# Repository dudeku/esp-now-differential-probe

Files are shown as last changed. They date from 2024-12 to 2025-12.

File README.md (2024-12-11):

# ESP-NOW Differential Probe Project

K. Dudek

### Framework: arduino-espressif32
>ver: 2.0.17
#### Lib Fixes:

```
in Ethernet.h
    class EthernetServer : public Server
    ->
    class EthernetServer : public Print
```

OR
```
in Ethernet.h in line 261:
	virtual void begin();
    ->
	virtual void begin(uint16_t port=0);

and in EthernetServer.cpp in line 28:
    void EthernetServer::begin()
    ->
    void EthernetServer::begin(uint16_t port_not_used)
```

#### Problems in framework version 3.x:
```
spi3 problem, not setting pinMode MISO (6)
[ ][E][esp32-hal-gpio.c:190] __digitalRead(): IO 6 is not set as GPIO.
```
### tool-esptoolpy @ 4.8.1

## Possible fix for framework 3.x
```
digitalRead() in LTC2449 lib cannot access MISO pin to check if transmission has been completed.

need to change LIC2449 library implementation for new version.
```

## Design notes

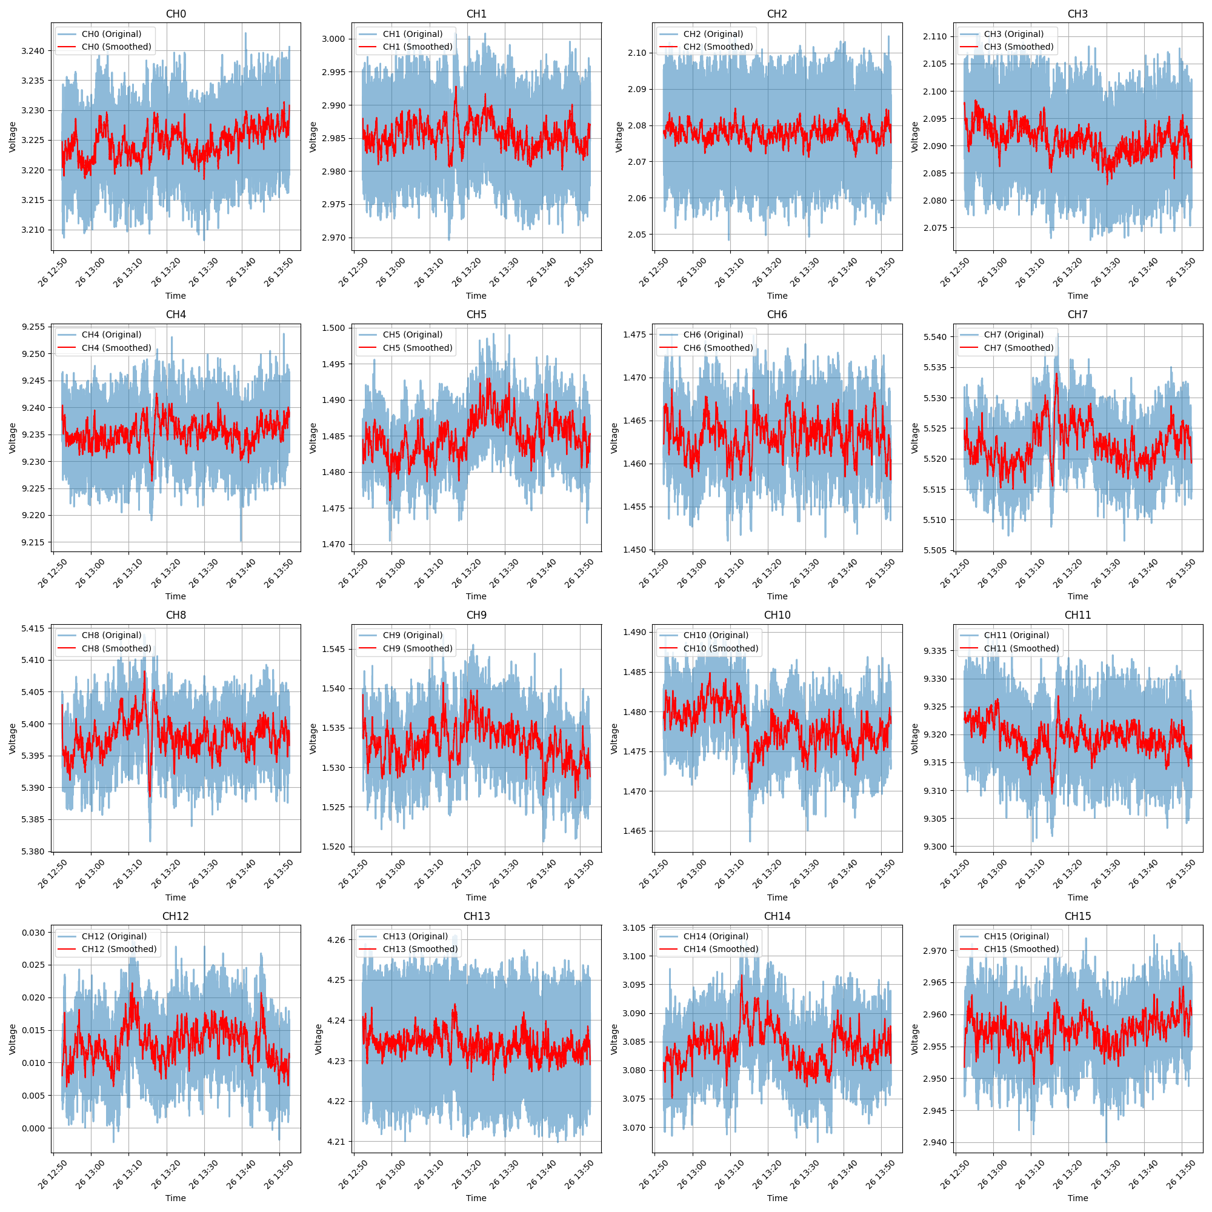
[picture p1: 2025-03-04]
scripts/graphs/espsonda_13-52-22_26-02-2025_2.png

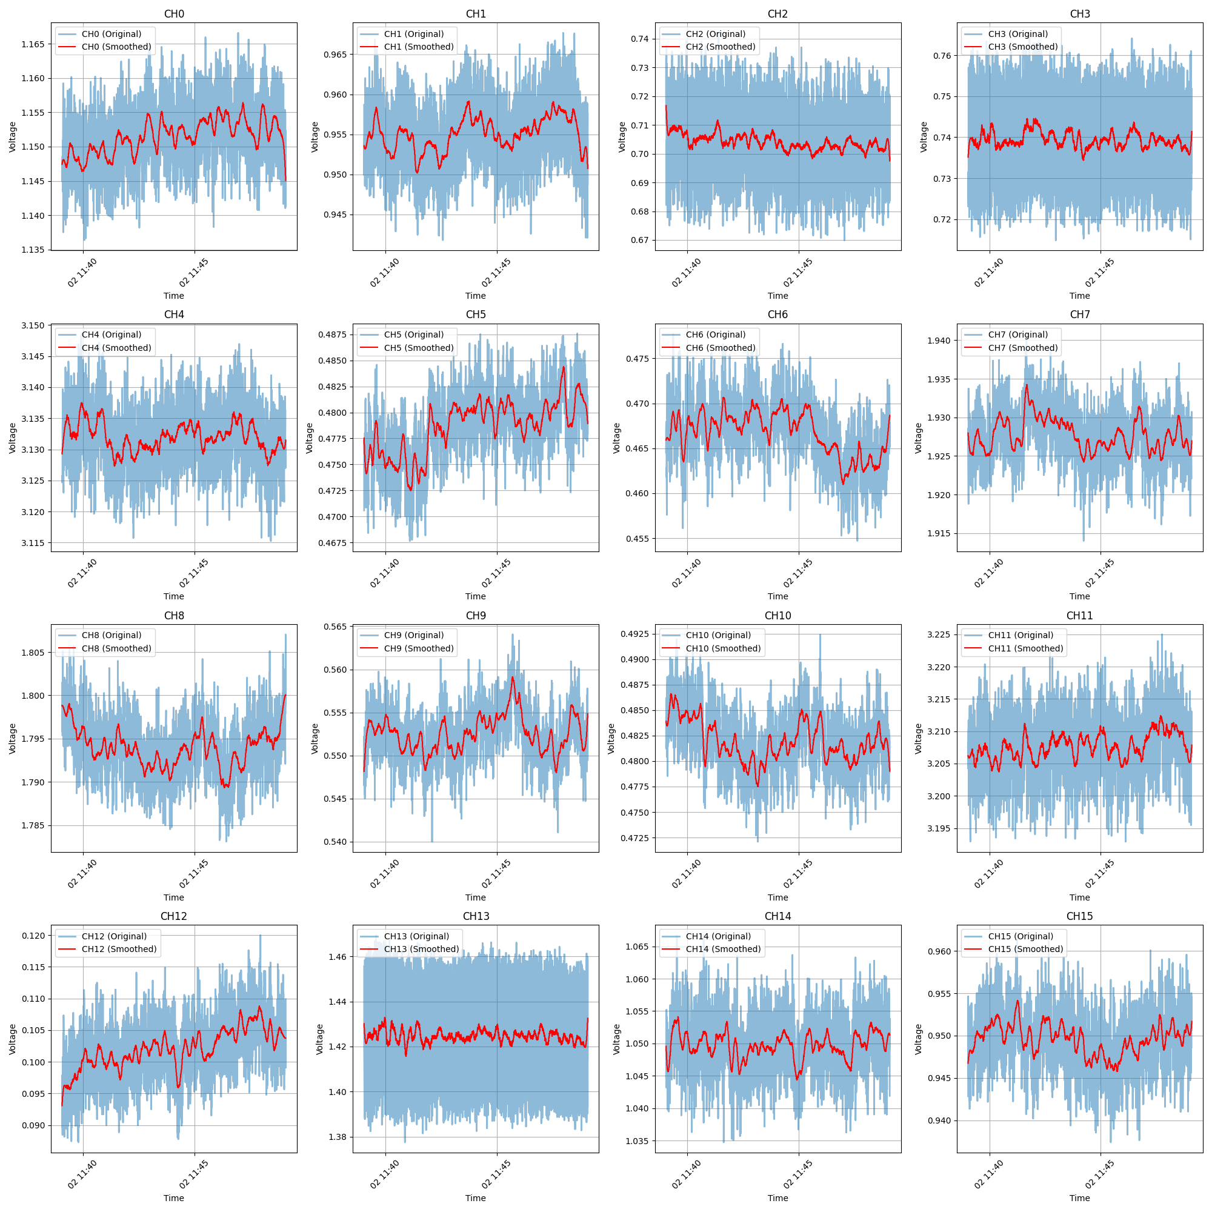
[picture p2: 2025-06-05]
scripts/graphs/espsonda_13-39-03_02-06-2025_2.png

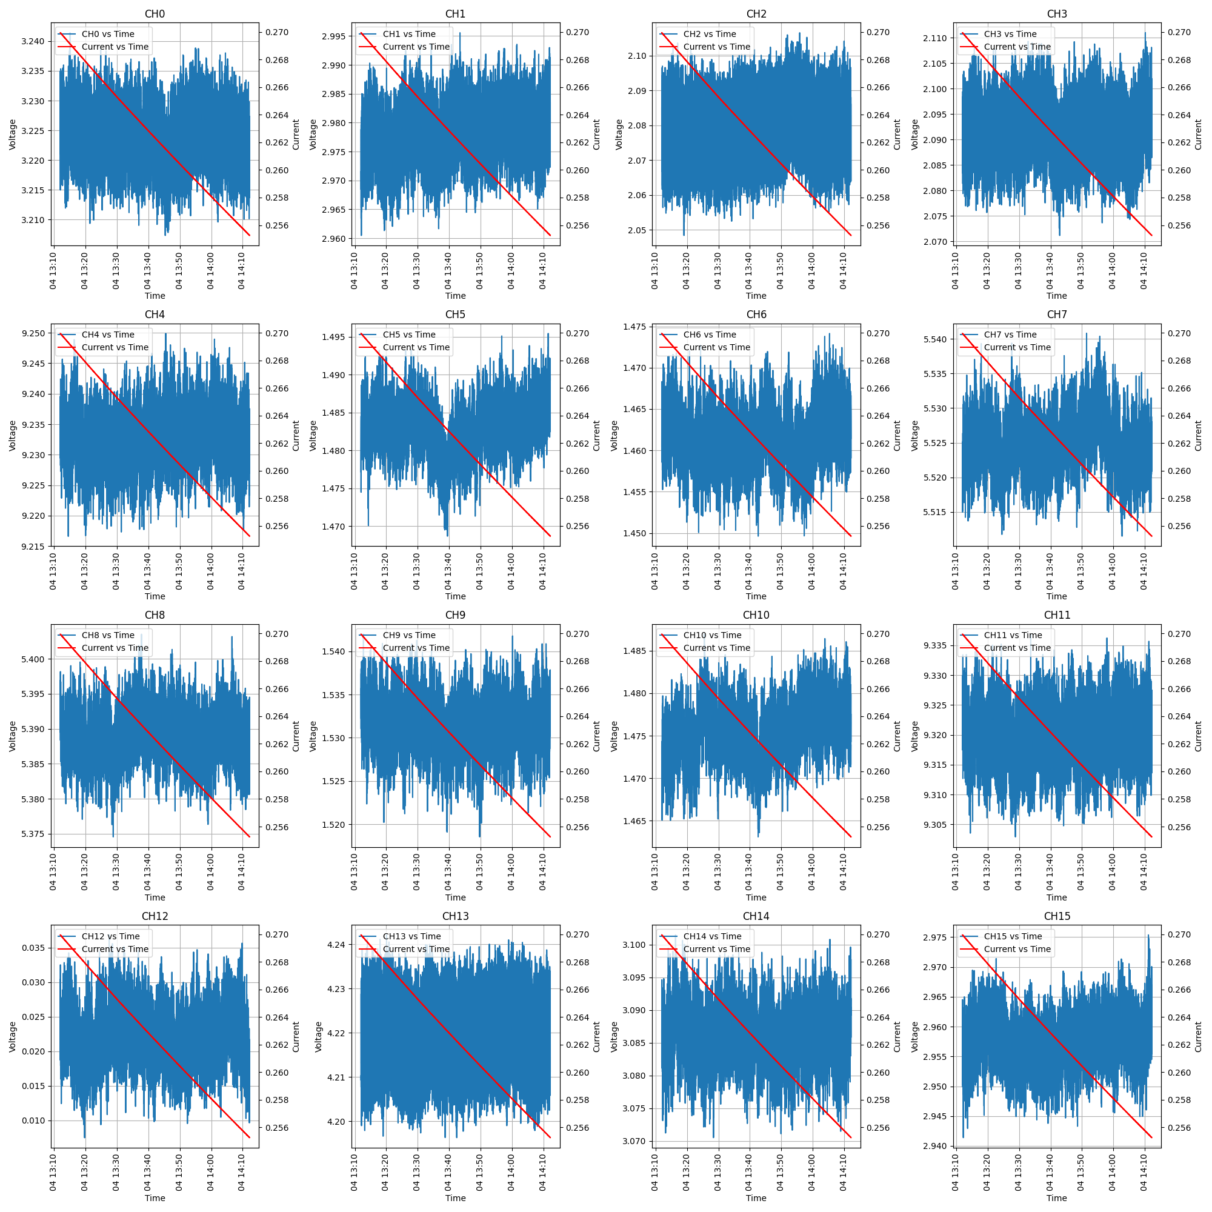
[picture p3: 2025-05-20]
scripts/graphs/espsonda_14-11-57_04-03-2025_1.png

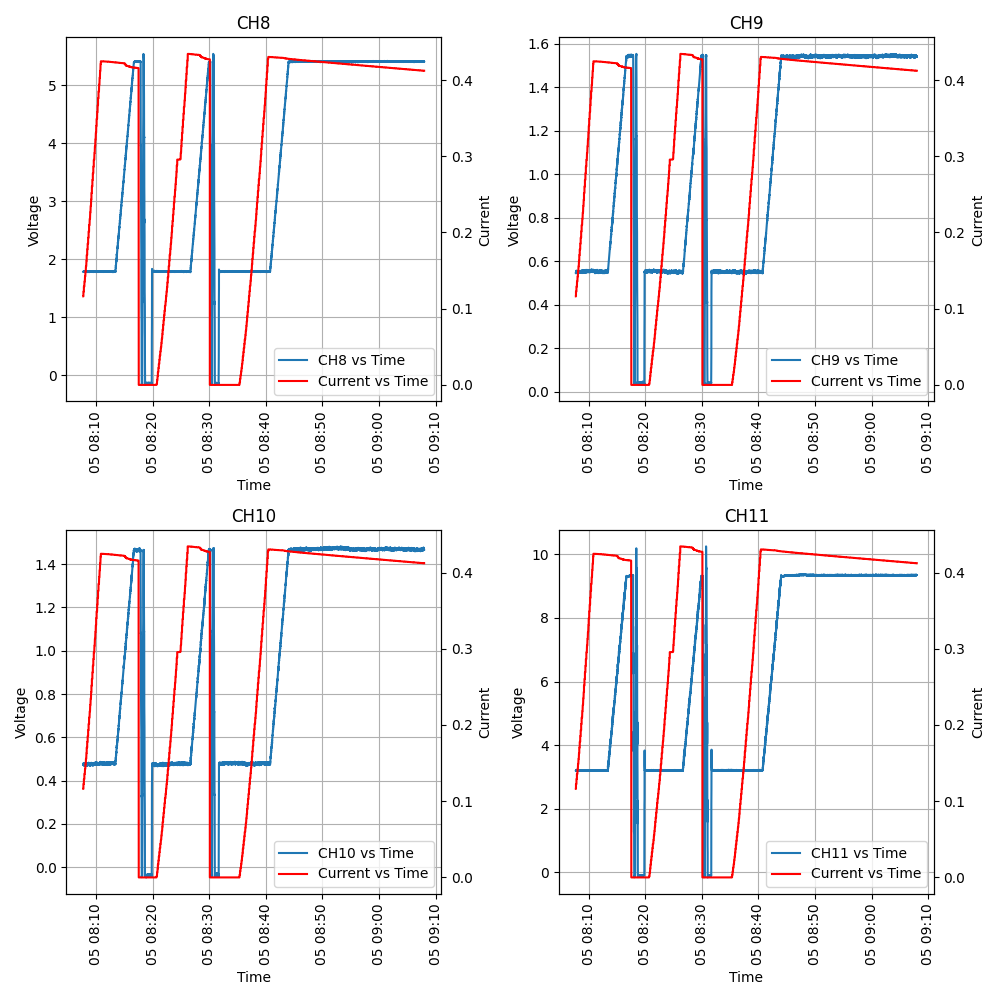
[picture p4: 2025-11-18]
scripts/graphs/espsonda_08-07-44_05-06-2025_fig3.png

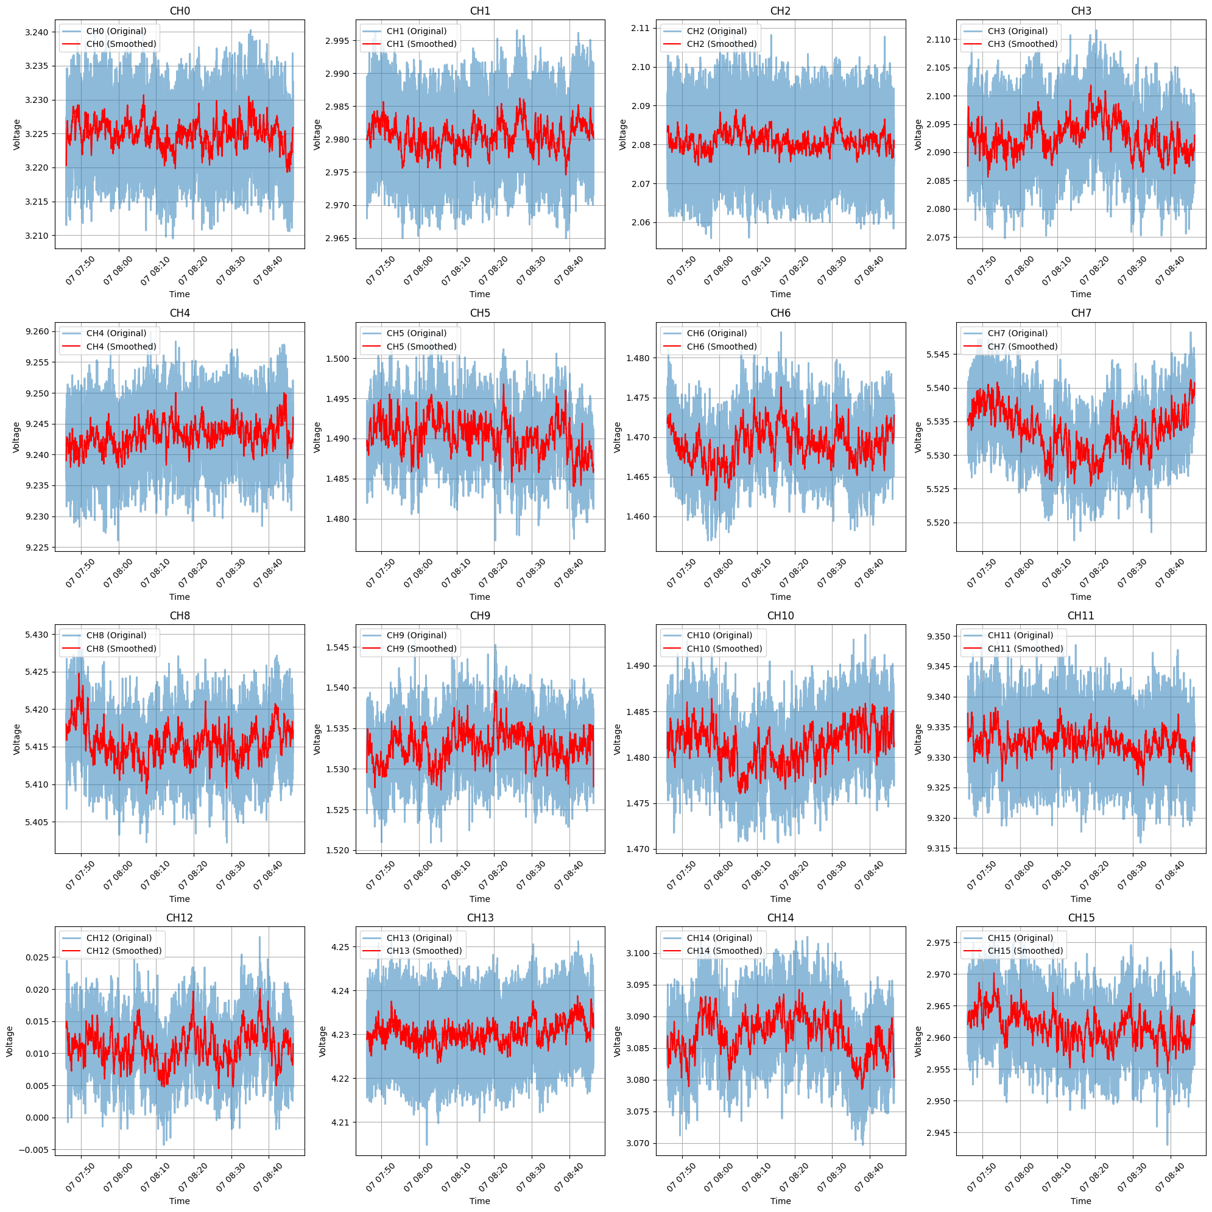
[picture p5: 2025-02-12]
scripts/graphs/1_5_GeV.png

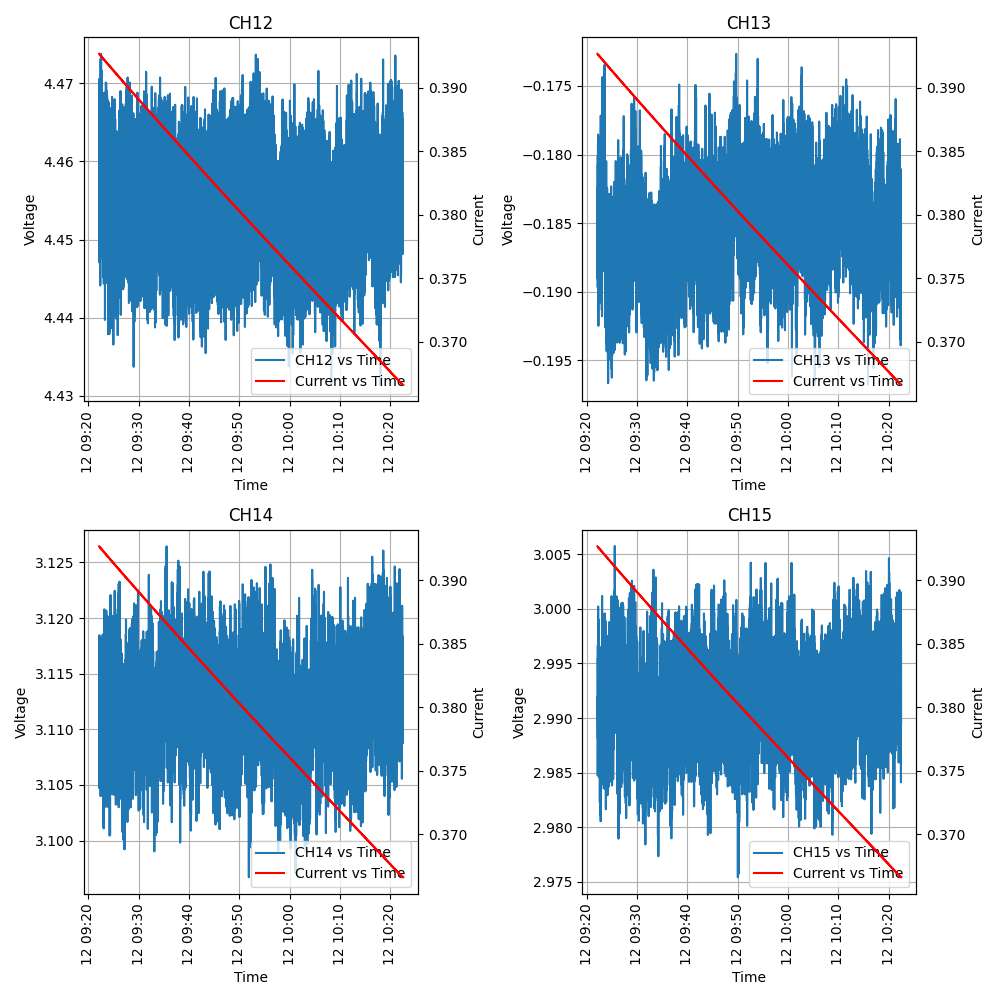
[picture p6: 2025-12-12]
scripts/graphs/espsonda_09-22-08_12-12-2025_fig4.png

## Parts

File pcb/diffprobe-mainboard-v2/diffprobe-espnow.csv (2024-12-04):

Id | Oznaczenie | Footprint | Liczba | Oznaczenie | Dostawca i numer artykułu
1 | C588,C546,C613,C640,C526,C521,C615,C635,C591,C554,C614,C600,C555,C622,C652,C566,C536,C535,C572,C647,C586,C527,C653,C610,C564,C649,C581,C578,C568,C625,C655,C562,C524,C542,C631,C590,C651,C633,C534,C514,C620,C582,C587,C660,C553,C629,C543,C531,C646,C537,C604,C540,C577,C549,C538,C529,C551,C592,C638,C560,C627,C576,C502,C563,C593,C552,C511,C626,C523,C619,C632,C545,C559,C602,C595,C525,C507,C561,C641,C599,C583,C659,C624,C510,C571,C522,C594,C628,C512,C658,C603,C636,C618,C518,C574,C516,C607,C506,C501,C609,C558,C548,C532,C584,C612,C648,C557,C596,C520,C517,C519,C528,C505,C579,C598,C503,C567,C608,C611,C654,C605,C513,C617,C643,C616,C565,C642,C637,C589,C606,C533,C634,C573,C575,C550,C585,C645,C547,C657,C601,C621,C630,C539,C556,C580,C541,C544,C656,C508,C504,C644,C509,C623,C639,C569,C530,C570,C650,C515,C597 | C_1206_3216Metric | 160 | 10 pF
2 | J12 | CONN12_5-2301994-8_TEC | 1 | 8P8C_LED_Shielded_x2
3 | R516,R657,R605,R602,R587,R617,R639,R576,R549,R552,R659,R633,R531,R590,R637,R569,R595,R640,R610,R543,R589,R574,R634,R528,R570,R598,R612,R556,R585,R555,R540,R575,R553,R594,R643,R523,R578,R519,R616,R517,R615,R582,R521,R646,R518,R507,R537,R638,R524,R560,R641,R592,R654,R631,R504,R565,R514,R550,R601,R649,R522,R545,R581,R619,R632,R520,R660,R635,R535,R611,R648,R606,R596,R534,R541,R505,R642,R502,R530,R644,R546,R566,R630,R658,R529,R627,R597,R593,R599,R588,R544,R557,R577,R600,R609,R510,R513,R625,R564,R628,R655,R562,R591,R629,R508,R608,R623,R650,R561,R653,R618,R547,R586,R559,R636,R651,R583,R515,R538,R647,R503,R572,R501,R539,R652,R624,R622,R558,R603,R512,R506,R571,R563,R573,R584,R511,R620,R656,R526,R613,R533,R604,R532,R542,R607,R567,R645,R509,R614,R568,R579,R626,R527,R548,R621,R554,R536,R551,R525,R580 | R_1206_3216Metric | 160 | 1 MOhms
4 | C106,C104 | C_0603_1608Metric | 2 | 10u
5 | R119,R120,R117,R121 | R_0603_1608Metric | 4 | 49R9
6 | J124,J116,J132,J131,J117,J112,J122,J105,J129,J118,J108,J123,J128,J106,J103,J113,J119,J107,J114,J130,J111,J110,J101,J121,J109,J115,J120,J102,J104,J127,J126,J125 | PinHeader_1x04_P2.54mm_Vertical | 32 | Conn_01x04_Socket
7 | J509,J504,J503,J505,J510,J507,J512,J508,J506,J516,J513,J502,J514,J501,J515,J511 | PhoenixContact_GMSTBA_2,5_2-G-7,62_1x02_P7.62mm_Horizontal | 16 | Screw_Terminal_01x02
8 | C105,C217,C218 | C_0603_1608Metric | 3 | 0.1u
9 | C108,C103,C101 | C_0603_1608Metric | 3 | 100n
10 | C120,C121,C116,C117,C112,C118,C119 | C_0603_1608Metric | 7 | 0.1uF
11 | D101 | D_0603_1608Metric | 1 | NSR20F30NXT5G
12 | R107 | R_0603_1608Metric | 1 | 1MEG
13 | C114,C124 | C_0603_1608Metric | 2 | 10nF
14 | R206,R213,R207,R210,R215,R204,R205,R214,R203,R212,R201,R216,R202,R208,R211,R209 | R_0603_1608Metric | 16 | 470R
15 | C202,C216,C206,C211,C201,C212,C214,C213,C210,C209,C207,C205,C203,C215,C204,C208,C223 | C_0603_1608Metric | 17 | 470pF
16 | R105,R101,R109,R102,R111,R110,R218 | R_0603_1608Metric | 7 | 10k
17 | C122,C113 | C_0603_1608Metric | 2 | 10uF
18 | R114,R115,R113,R112 | R_0603_1608Metric | 4 | 33R
19 | R123,R122 | R_0603_1608Metric | 2 | 330
20 | U103 | LQFP-48_7x7mm_P0.5mm | 1 | W5500
21 | J11 | USB_C_Receptacle_GCT_USB4105-xx-A_16P_TopMnt_Horizontal | 1 | USB_C_Receptacle_USB2.0
22 | SW103 | SW_PUSH_E-Switch_500SDP1S1M2QEA | 1 | 500SDP1S1M2QEA
23 | C302,C301 | C_Rect_L13.0mm_W4.0mm_P10.00mm_FKS3_FKP3_MKS4 | 2 | 22nF
24 | SW102,SW101 | SW_Push_1P1T_NO_CK_KMR2 | 2 | SW_Push
25 | U101 | ESP32-S3-WROOM-1U | 1 | ESP32-S3-WROOM-1
26 | R118 | R_0603_1608Metric | 1 | 10
27 | R106,R217 | R_0603_1608Metric | 2 | 1k
28 | C305,C102,C303,C107 | C_0603_1608Metric | 4 | 1u
29 | C111,C110 | C_0603_1608Metric | 2 | 18pF
30 | R108 | R_0603_1608Metric | 1 | 0R
31 | R104,R103 | R_0603_1608Metric | 2 | 5.1k
32 | C123 | C_0603_1608Metric | 1 | 22nF
33 | D102 | LED_0603_1608Metric | 1 | LED
34 | J54 | Pin_D1.4mm_L8.5mm_W2.8mm_FlatFork | 1 | AC_P
35 | C127 | C_0603_1608Metric | 1 | 1nF
36 | F1 | Fuse_Littelfuse_372_D8.50mm | 1 | 37213150431
37 | C304,C306 | CP_Elec_10x12.5 | 2 | 100u
38 | FL1 | Choke_EPCOS_B82722A | 1 | EPCOS B82722A2202N001
39 | RV2,RV1 | RV_Disc_D9mm_W4.2mm_P5mm | 2 | B72207S0251K101
40 | C126,C125 | C_0603_1608Metric | 2 | 6.8nF
41 | Y101 | Crystal_SMD_HC49-SD | 1 | DF18CC1-25.000MHZ-T
42 | J56 | Pin_D1.4mm_L8.5mm_W2.8mm_FlatFork | 1 | AC_E
43 | C219 | C_0603_1608Metric | 1 | 4n7F
44 | PS1 | CONV_TML_20205 | 1 | TML_20205
45 | R116 | R_0603_1608Metric | 1 | 12.4k 1%
46 | J55 | Pin_D1.4mm_L8.5mm_W2.8mm_FlatFork | 1 | AC_N
47 | U105 | SOT-23-6 | 1 | USBLC6-2SC6
48 | U102 | QFN-38-1EP_5x7mm_P0.5mm_EP3.15x5.15mm | 1 | LTC2448CUHF-PBF
49 | C115 | C_0603_1608Metric | 1 | 4.7uF
50 | U107 | TSSOP-20_4.4x6.5mm_P0.65mm | 1 | TXB0108DQSR
51 | U106 | SOT-23-5 | 1 | LM4030-2.5
52 | L101 | L_0603_1608Metric | 1 | BLM18PG121SN1D
53 | C109 | C_0603_1608Metric | 1 | 4.7u
54 | U104 | SOT-223-3_TabPin2 | 1 | LDL1117S33R

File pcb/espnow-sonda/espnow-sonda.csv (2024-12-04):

Id | Oznaczenie | Footprint | Liczba | Oznaczenie | Dostawca i numer artykułu
1 | C19,C15,C14,C18 | C_0603_1608Metric | 4 | 1 µF
2 | TP3,TP1,TP2,TP4,TP5 | TestPoint_Pad_D1.5mm | 5 | Test Point
3 | R21,R22,R19,R24,R20 | R_0603_1608Metric | 5 | 348 Ohms
4 | D2,D4,D3,D1 | D_SOD-323 | 4 | BAS316,115
5 | C6,C3 | C_0603_1608Metric | 2 | 470pF
6 | J2,J1 | PinHeader_1x04_P2.54mm_Vertical | 2 | Conn_01x04_Pin
7 | C5,C2 | C_0603_1608Metric | 2 | 510pF
8 | R8,R10 | R_0603_1608Metric | 2 | 24.9 Ohms
9 | L1,L2 | L_0603_1608Metric | 2 | 22 nH
10 | R5,R4,R14,R13 | R_0603_1608Metric | 4 | 150 Ohms
11 | U1 | MSOP-8-1EP_3x3mm_P0.65mm_EP1.68x1.88mm | 1 | LTC6269xMS8E
12 | R16 | R_0603_1608Metric | 1 | 2.05k
13 | R18,R17 | R_0603_1608Metric | 2 | 470 Ohms
14 | C10,C11,C9 | C_0603_1608Metric | 3 | 10 pF
15 | C4,C1 | C_Trimmer_Voltronics_JZ | 2 | JZ400
16 | R7,R11 | R_0603_1608Metric | 2 | 845 Ohms
17 | U3 | SOT-23-6 | 1 | LMH6611
18 | R15 | R_0603_1608Metric | 1 | 110
19 | R6,R12 | R_0603_1608Metric | 2 | 9.1 kOhms
20 | R1,R3 | R_0603_1608Metric | 2 | 15 kOhms
21 | U2 | SOT-23-3 | 1 | XC6206P251
22 | U4 | SOT-23-3 | 1 | XC6902N251
23 | C13,C17,C12,C16 | C_0603_1608Metric | 4 | 0.1 µF
24 | C8,C7 | C_0603_1608Metric | 2 | 10pF
25 | R23 | R_0603_1608Metric | 1 | 1 kOhms
26 | R9 | Potentiometer_Bourns_3006W_Horizontal | 1 | 100 Ohms
27 | R2 | Potentiometer_Bourns_3006W_Horizontal | 1 | 1 MOhms

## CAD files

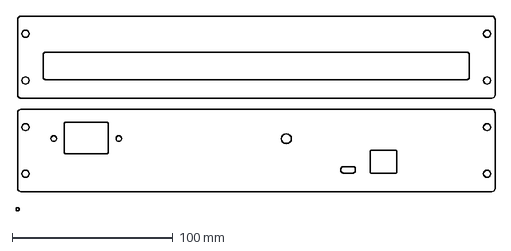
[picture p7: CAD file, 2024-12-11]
case/fpbp_sonda.dxf
297.6 x 121.1 mm

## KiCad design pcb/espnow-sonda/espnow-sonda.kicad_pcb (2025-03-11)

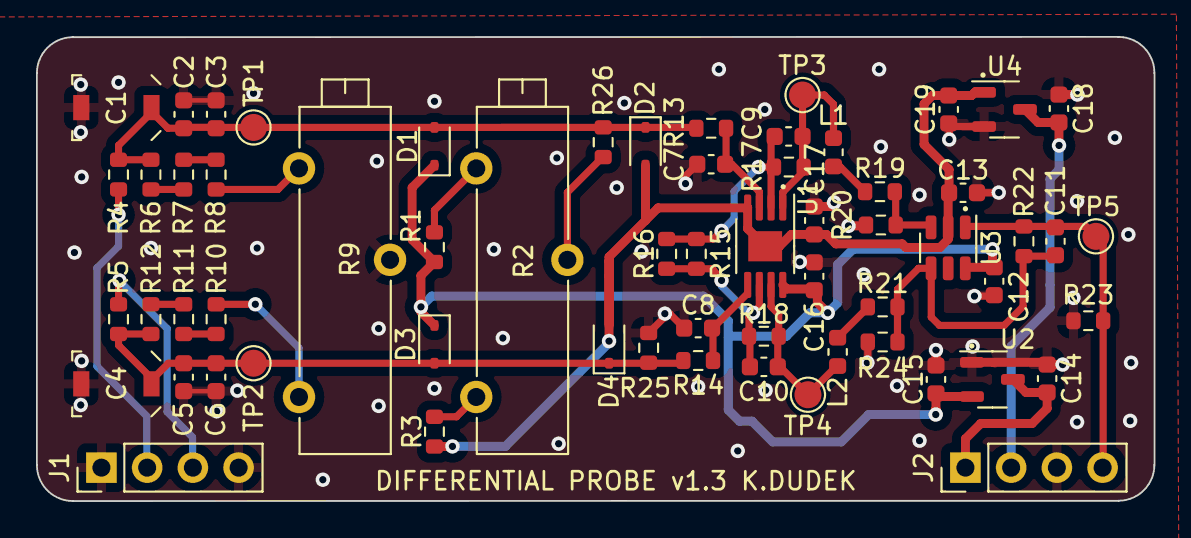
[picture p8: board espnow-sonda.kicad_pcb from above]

Board: 2 copper layers, 62.1 x 25.8 mm, 62 parts (0 on the bottom side), 29 nets.

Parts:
C1, C4: C_Trimmer_Voltronics_JZ
C2, C3, C5, C6: C_0603_1608Metric
C7, C8, C9, C10, C11: 10p; C_0603_1608Metric
C12, C13, C16, C17: 0.1µ; C_0603_1608Metric
C14, C15, C18, C19: 1µ; C_0603_1608Metric
D1, D2, D3, D4: BAS316,115; D_SOD-323
J1, J2: PinHeader_1x04_P2.54mm_Vertical
L1, L2: r0; L_0603_1608Metric
R1, R3: 1M; R_0603_1608Metric
R2: 1M; Potentiometer_Bourns_3006W_Horizontal
R4, R5, R13, R14: 150; R_0603_1608Metric
R6, R12: 9.1k; R_0603_1608Metric
R7, R11: 845; R_0603_1608Metric
R8, R10: 24.9; R_0603_1608Metric
R9: 100; Potentiometer_Bourns_3006W_Horizontal
R15: 16; R_0603_1608Metric
R16, R24: R_0603_1608Metric
R17, R18: 470; R_0603_1608Metric
R19, R20, R21, R22: 348; R_0603_1608Metric
R23: 1k; R_0603_1608Metric
R25, R26: 750k; R_0603_1608Metric
TP1, TP2, TP4, TP5: TestPoint_Pad_D1.5mm
TP3: Test Point; TestPoint_Pad_D1.5mm
U1: LTC6269; MSOP-8-1EP_3x3mm_P0.65mm_EP1.68x1.88mm
U2: XC6206P251; SOT-23-3
U3: LMH6611; SOT-23-6
U4: XC6902N251; SOT-23-3

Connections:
4V8: C12.2, C15.2, C16.2, D1.1, D3.1, R1.1, U1.8 (V+), U2.2 (VO), U3.6 (V+)
-4V8: C13.2, C17.2, C19.2, D2.2, D4.2, R3.2, U1.4 (V-), U1.9 (V-), U3.2 (V-), U4.1 (VO)
/IN_N: J1.3, R5.1
/IN_P: J1.2, R4.1
/VCC5V: C14.2, J2.1, U2.3 (VI)
/VEE-5V: C18.2, J2.2, U4.3 (VI)
/VOUT: C11.2, J2.4, R22.2, R23.2, TP5.1 (TP), U3.1
GND: C1.2, C2.1, C3.1, C4.2, C5.1, C6.1, C7.1, C8.1, C12.1, C13.1, C14.1, C15.1, C16.1, C17.1, C18.1, C19.1, J1.1, J1.4, J2.3, R9.2, R20.2, R23.1, R24.1, R25.1, U2.1 (GND), U4.2 (GND)
unnamed: L1.2, R19.1
unnamed: L2.2, R21.1
unnamed: R1.2, R2.3
unnamed: R2.1, R3.1
unnamed: R2.2, R26.1
unnamed: R6.1, R7.2
unnamed: R7.1, R8.2
unnamed: R8.1, R9.3
unnamed: R9.1, R10.1
unnamed: R10.2, R11.1
unnamed: R11.2, R12.1
unnamed: C1.1, C2.2, C3.2, D1.2, D2.1, R4.2, R6.2, R13.1, R26.2, TP1.1 (TP)
unnamed: C4.1, C5.2, C6.2, D3.2, D4.1, R5.2, R12.2, R14.1, R25.2, TP2.1 (TP)
unnamed: C9.2, L1.1, R17.2, TP3.1 (TP), U1.1
unnamed: C10.2, L2.1, R18.2, TP4.1 (TP), U1.7
unnamed: C7.2, R13.2, U1.3 (+)
unnamed: C9.1, R15.1, R16.1, R17.1, U1.2 (-)
unnamed: C8.2, R14.2, U1.5 (+)
unnamed: C10.1, R15.2, R16.2, R18.1, U1.6 (-)
unnamed: R19.2, R20.1, U3.3 (+)
unnamed: C11.1, R21.2, R22.1, R24.2, U3.4 (-)

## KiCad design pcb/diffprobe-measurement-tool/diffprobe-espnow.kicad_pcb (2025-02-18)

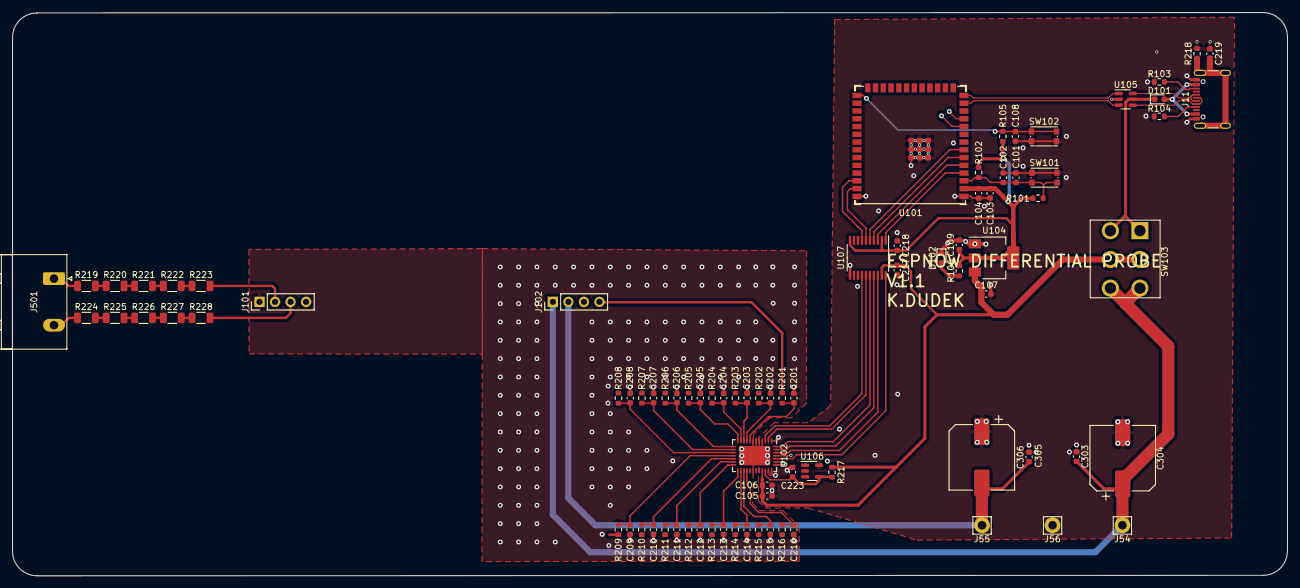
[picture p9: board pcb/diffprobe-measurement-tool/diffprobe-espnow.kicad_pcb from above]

Board: 2 copper layers, 208.6 x 92.2 mm, 85 parts (0 on the bottom side), 59 nets.

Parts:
C101, C103, C108: 100n; C_0603_1608Metric
C102, C107, C303, C305: 1u; C_0603_1608Metric
C104, C106: 10u; C_0603_1608Metric
C105, C217, C218: 0.1u; C_0603_1608Metric
C109: 4.7u; C_0603_1608Metric
C201, C202, C203, C204, C205, C206, C207, C208, C209, C210, C211, C212, C213, C214, C215, C216, C223: 470pF; C_0603_1608Metric
C219: 4n7F; C_0603_1608Metric
C304, C306: 100u; CP_Elec_10x12.5
D101: NSR20F30NXT5G; D_0603_1608Metric
D102: LED; LED_0603_1608Metric
J11: USB_C_Receptacle_USB2.0; USB_C_Receptacle_GCT_USB4105-xx-A_16P_TopMnt_Horizontal
J54: 5V; Pin_D1.4mm_L8.5mm_W2.8mm_FlatFork
J55: -5V; Pin_D1.4mm_L8.5mm_W2.8mm_FlatFork
J56: GND; Pin_D1.4mm_L8.5mm_W2.8mm_FlatFork
J101, J102: Conn_01x04_Socket; PinHeader_1x04_P2.54mm_Vertical
J501: Screw_Terminal_01x02; PhoenixContact_GMSTBA_2,5_2-G-7,62_1x02_P7.62mm_Horizontal
R101, R102, R105: 10k; R_0603_1608Metric
R103, R104: 5.1k; R_0603_1608Metric
R106, R217: 1k; R_0603_1608Metric
R201: 100k; R_0603_1608Metric
R202, R203, R204, R205, R206, R207, R208, R209, R210, R211, R212, R213, R214, R215, R216: 470R; R_0603_1608Metric
R218: 1MEG; R_0603_1608Metric
R219, R220, R221, R222, R223, R224, R225, R226, R227, R228: 1MEG; R_1206_3216Metric
SW101, SW102: SW_Push; SW_Push_1P1T_NO_CK_KMR2
SW103: 500SDP1S1M2QEA; SW_PUSH_E-Switch_500SDP1S1M2QEA
U101: ESP32-S3-WROOM-1; ESP32-S3-WROOM-1U
U102: LTC2448CUHF-PBF; QFN-38-1EP_5x7mm_P0.5mm_EP3.15x5.15mm
U104: LDL1117S33R; SOT-223-3_TabPin2
U105: USBLC6-2SC6; SOT-23-6
U106: LM4030-2.5; SOT-23-5
U107: TXB0108PW; TSSOP-20_4.4x6.5mm_P0.65mm

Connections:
/PS5V: C303.1, C304.1, J54.1, J102.1, SW103.3 (C), SW103.6 (C)
/PS-5V: C305.1, C306.2, J55.1, J102.2
/esp32andadc/CH0: J102.4, R201.2
/esp32andadc/D+: U101.14 (GPIO20/U1CTS/ADC2_CH9/CLK_OUT1/USB_D+), U105.1 (I/O1)
/esp32andadc/D-: U101.13 (GPIO19/U1RTS/ADC2_CH8/CLK_OUT2/USB_D-), U105.3 (I/O2)
/esp32andadc/Din+: J11.A6 (D+), J11.B6 (D+), U105.6 (I/O1)
/esp32andadc/Din-: J11.A7 (D-), J11.B7 (D-), U105.4 (I/O2)
/esp32andadc/SHIELD: C219.2, J11.S1 (SHIELD), R218.1
/esp32andadc/USB5V: D101.1 (K), SW103.1 (A), SW103.4 (A), U105.5 (VBUS)
/esp32andadc/VCC3V3: C103.1, C104.1, C109.1, C218.2, R101.1, R102.1, R105.1, R106.1, U101.2 (3V3), U104.2 (VO), U107.2 (VCCA), U107.10 (OE)
/esp32andadc/VCC5V: C105.1, C106.1, C107.1, C217.1, R217.1, SW103.2 (B), SW103.5 (B), U102.28 (VCC), U104.3 (VI), U107.19 (VCCB)
GND: C101.2, C102.2, C103.2, C104.2, C105.2, C106.2, C107.2, C108.2, C109.2, C201.2, C202.2, C203.2, C204.2, C205.2, C206.2, C207.2, C208.2, C209.2, C210.2, C211.2, C212.2, C213.2, C214.2, C215.2, C216.2, C217.2, C218.1, C219.1, C223.2, C303.2, C304.2, C305.2, C306.1, D102.1 (K), J11.A1 (GND), J11.A12 (GND), J11.B1 (GND), J11.B12 (GND), J56.1, J101.1, J101.4, J102.3, R103.2, R104.2, R218.2, SW101.1, SW102.2, U101.1 (GND), U101.40 (GND), U101.41 (GND), U102.1 (GND), U102.4 (GND), U102.5 (GND), U102.6 (GND), U102.7 (COM), U102.30 (REF-), U102.31 (GND), U102.32 (GND), U102.33 (GND), U102.35 (FO), U102.39 (EPAD), U104.1 (GND), U105.2 (GND), U106.5 (A), U107.11 (GND)
unnamed: D101.2 (A), J11.A4 (VBUS), J11.A9 (VBUS), J11.B4 (VBUS), J11.B9 (VBUS)
unnamed: D102.2 (A), R106.2
unnamed: J11.A5 (CC1), R104.1
unnamed: J11.B5 (CC2), R103.1
unnamed: J101.2, R223.2
unnamed: J101.3, R228.2
unnamed: J501.1, R219.1
unnamed: J501.2, R224.1
unnamed: R219.2, R220.1
unnamed: R220.2, R221.1
unnamed: R221.2, R222.1
unnamed: R222.2, R223.1
unnamed: R224.2, R225.1
unnamed: R225.2, R226.1
unnamed: R226.2, R227.1
unnamed: R227.2, R228.1
unnamed: C101.1, C102.1, R101.2, R102.2, SW101.2, U101.3 (EN)
unnamed: C108.1, R105.2, SW102.1, U101.27 (GPIO0/BOOT)
unnamed: U101.39 (GPIO1/TOUCH1/ADC1_CH0), U107.6 (A5)
unnamed: U101.38 (GPIO2/TOUCH2/ADC1_CH1), U107.7 (A6)
unnamed: U101.4 (GPIO4/TOUCH4/ADC1_CH3), U107.1 (A1)
unnamed: U101.5 (GPIO5/TOUCH5/ADC1_CH4), U107.3 (A2)
unnamed: U101.6 (GPIO6/TOUCH6/ADC1_CH5), U107.4 (A3)
unnamed: U101.7 (GPIO7/TOUCH7/ADC1_CH6), U107.5 (A4)
unnamed: U102.36 (*CS), U107.18 (B2)
unnamed: U102.3 (*EXT), U107.14 (B6)
unnamed: U102.2 (BUSY), U107.15 (B5)
unnamed: C201.1, R201.1, U102.8 (CH0)
unnamed: C202.1, R202.1, U102.9 (CH1)
unnamed: C203.1, R203.1, U102.10 (CH2)
unnamed: C204.1, R204.1, U102.11 (CH3)
unnamed: C205.1, R205.1, U102.12 (CH4)
unnamed: C206.1, R206.1, U102.13 (CH5)
unnamed: C207.1, R207.1, U102.14 (CH6)
unnamed: C208.1, R208.1, U102.15 (CH7)
unnamed: C209.1, R209.2, U102.16 (CH8)
unnamed: C210.1, R210.2, U102.17 (CH9)
unnamed: C211.1, R211.2, U102.18 (CH10)
unnamed: C212.1, R212.2, U102.19 (CH11)
unnamed: C213.1, R213.1, U102.20 (CH12)
unnamed: C214.1, R214.1, U102.21 (CH13)
unnamed: C215.1, R215.1, U102.22 (CH14)
unnamed: C216.1, R216.1, U102.23 (CH15)
unnamed: C223.1, R217.2, U102.29 (REF+), U106.4 (K)
unnamed: U102.38 (SCK), U107.16 (B4)
unnamed: U102.34 (SDI), U107.20 (B1)
unnamed: U102.37 (SDO), U107.17 (B3)

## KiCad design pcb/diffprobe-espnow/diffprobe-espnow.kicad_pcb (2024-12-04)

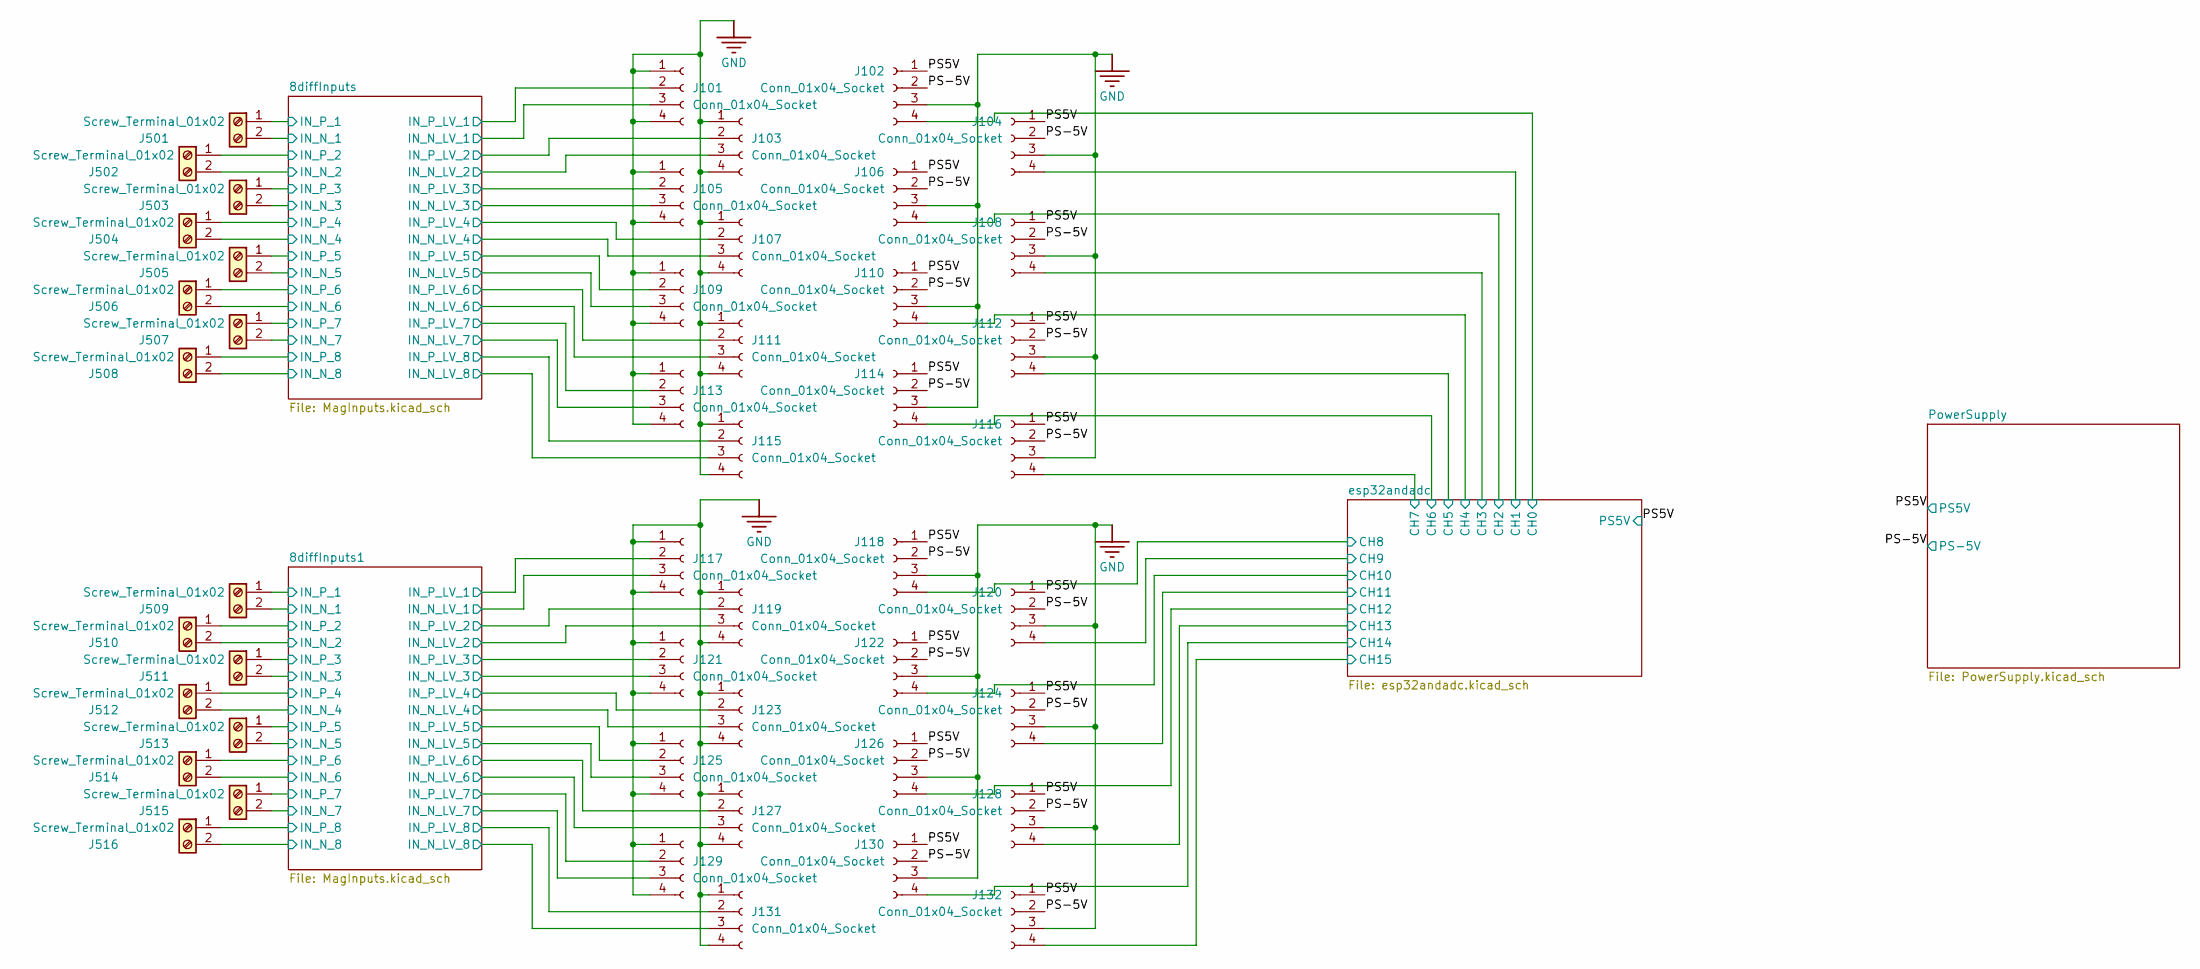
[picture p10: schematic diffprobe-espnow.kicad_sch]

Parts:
J101, J102, J103, J104, J105, J106, J107, J108, J109, J110, J111, J112, J113, J114, J115, J116, J117, J118, J119, J120, J121, J122, J123, J124, J125, J126, J127, J128, J129, J130, J131, J132: Conn_01x04_Socket; PinHeader_1x04_P2.54mm_Vertical
J501, J502, J503, J504, J505, J506, J507, J508, J509, J510, J511, J512, J513, J514, J515, J516: Screw_Terminal_01x02; PhoenixContact_GMSTBA_2,5_2-G-7,62_1x02_P7.62mm_Horizontal

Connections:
/8diffInputs1/IN_N_1: J509.2; also elsewhere on the board
/8diffInputs1/IN_N_2: J510.2; also elsewhere on the board
/8diffInputs1/IN_N_3: J511.2; also elsewhere on the board
/8diffInputs1/IN_N_4: J512.2; also elsewhere on the board
/8diffInputs1/IN_N_5: J513.2; also elsewhere on the board
/8diffInputs1/IN_N_6: J514.2; also elsewhere on the board
/8diffInputs1/IN_N_7: J515.2; also elsewhere on the board
/8diffInputs1/IN_N_8: J516.2; also elsewhere on the board
/8diffInputs1/IN_N_LV_1: J117.3; also elsewhere on the board
/8diffInputs1/IN_N_LV_2: J119.3; also elsewhere on the board
/8diffInputs1/IN_N_LV_3: J121.3; also elsewhere on the board
/8diffInputs1/IN_N_LV_4: J123.3; also elsewhere on the board
/8diffInputs1/IN_N_LV_5: J125.3; also elsewhere on the board
/8diffInputs1/IN_N_LV_6: J127.3; also elsewhere on the board
/8diffInputs1/IN_N_LV_7: J129.3; also elsewhere on the board
/8diffInputs1/IN_N_LV_8: J131.3; also elsewhere on the board
/8diffInputs1/IN_P_1: J509.1; also elsewhere on the board
/8diffInputs1/IN_P_2: J510.1; also elsewhere on the board
/8diffInputs1/IN_P_3: J511.1; also elsewhere on the board
/8diffInputs1/IN_P_4: J512.1; also elsewhere on the board
/8diffInputs1/IN_P_5: J513.1; also elsewhere on the board
/8diffInputs1/IN_P_6: J514.1; also elsewhere on the board
/8diffInputs1/IN_P_7: J515.1; also elsewhere on the board
/8diffInputs1/IN_P_8: J516.1; also elsewhere on the board
/8diffInputs1/IN_P_LV_1: J117.2; also elsewhere on the board
/8diffInputs1/IN_P_LV_2: J119.2; also elsewhere on the board
/8diffInputs1/IN_P_LV_3: J121.2; also elsewhere on the board
/8diffInputs1/IN_P_LV_4: J123.2; also elsewhere on the board
/8diffInputs1/IN_P_LV_5: J125.2; also elsewhere on the board
/8diffInputs1/IN_P_LV_6: J127.2; also elsewhere on the board
/8diffInputs1/IN_P_LV_7: J129.2; also elsewhere on the board
/8diffInputs1/IN_P_LV_8: J131.2; also elsewhere on the board
/8diffInputs/IN_N_1: J501.2; also elsewhere on the board
/8diffInputs/IN_N_2: J502.2; also elsewhere on the board
/8diffInputs/IN_N_3: J503.2; also elsewhere on the board
/8diffInputs/IN_N_4: J504.2; also elsewhere on the board
/8diffInputs/IN_N_5: J505.2; also elsewhere on the board
/8diffInputs/IN_N_6: J506.2; also elsewhere on the board
/8diffInputs/IN_N_7: J507.2; also elsewhere on the board
/8diffInputs/IN_N_8: J508.2; also elsewhere on the board
/8diffInputs/IN_N_LV_1: J101.3; also elsewhere on the board
/8diffInputs/IN_N_LV_2: J103.3; also elsewhere on the board
/8diffInputs/IN_N_LV_3: J105.3; also elsewhere on the board
/8diffInputs/IN_N_LV_4: J107.3; also elsewhere on the board
/8diffInputs/IN_N_LV_5: J109.3; also elsewhere on the board
/8diffInputs/IN_N_LV_6: J111.3; also elsewhere on the board
/8diffInputs/IN_N_LV_7: J113.3; also elsewhere on the board
/8diffInputs/IN_N_LV_8: J115.3; also elsewhere on the board
/8diffInputs/IN_P_1: J501.1; also elsewhere on the board
/8diffInputs/IN_P_2: J502.1; also elsewhere on the board
/8diffInputs/IN_P_3: J503.1; also elsewhere on the board
/8diffInputs/IN_P_4: J504.1; also elsewhere on the board
/8diffInputs/IN_P_5: J505.1; also elsewhere on the board
/8diffInputs/IN_P_6: J506.1; also elsewhere on the board
/8diffInputs/IN_P_7: J507.1; also elsewhere on the board
/8diffInputs/IN_P_8: J508.1; also elsewhere on the board
/8diffInputs/IN_P_LV_1: J101.2; also elsewhere on the board
/8diffInputs/IN_P_LV_2: J103.2; also elsewhere on the board
/8diffInputs/IN_P_LV_3: J105.2; also elsewhere on the board
/8diffInputs/IN_P_LV_4: J107.2; also elsewhere on the board
/8diffInputs/IN_P_LV_5: J109.2; also elsewhere on the board
/8diffInputs/IN_P_LV_6: J111.2; also elsewhere on the board
/8diffInputs/IN_P_LV_7: J113.2; also elsewhere on the board
/8diffInputs/IN_P_LV_8: J115.2; also elsewhere on the board
/PS5V: J102.1, J104.1, J106.1, J108.1, J110.1, J112.1, J114.1, J116.1, J118.1, J120.1, J122.1, J124.1, J126.1, J128.1, J130.1, J132.1; also elsewhere on the board
/PS-5V: J102.2, J104.2, J106.2, J108.2, J110.2, J112.2, J114.2, J116.2, J118.2, J120.2, J122.2, J124.2, J126.2, J128.2, J130.2, J132.2; also elsewhere on the board
/esp32andadc/CH0: J102.4; also elsewhere on the board
/esp32andadc/CH1: J104.4; also elsewhere on the board
/esp32andadc/CH2: J106.4; also elsewhere on the board
/esp32andadc/CH3: J108.4; also elsewhere on the board
/esp32andadc/CH4: J110.4; also elsewhere on the board
/esp32andadc/CH5: J112.4; also elsewhere on the board
/esp32andadc/CH6: J114.4; also elsewhere on the board
/esp32andadc/CH7: J116.4; also elsewhere on the board
/esp32andadc/CH8: J118.4; also elsewhere on the board
/esp32andadc/CH9: J120.4; also elsewhere on the board
/esp32andadc/CH10: J122.4; also elsewhere on the board
/esp32andadc/CH11: J124.4; also elsewhere on the board
/esp32andadc/CH12: J126.4; also elsewhere on the board
/esp32andadc/CH13: J128.4; also elsewhere on the board
/esp32andadc/CH14: J130.4; also elsewhere on the board
/esp32andadc/CH15: J132.4; also elsewhere on the board
GND: J101.1, J101.4, J102.3, J103.1, J103.4, J104.3, J105.1, J105.4, J106.3, J107.1, J107.4, J108.3, J109.1, J109.4, J110.3, J111.1, J111.4, J112.3, J113.1, J113.4, J114.3, J115.1, J115.4, J116.3, J117.1, J117.4, J118.3, J119.1, J119.4, J120.3, J121.1, J121.4, J122.3, J123.1, J123.4, J124.3, J125.1, J125.4, J126.3, J127.1, J127.4, J128.3, J129.1, J129.4, J130.3, J131.1, J131.4, J132.3; also elsewhere on the board

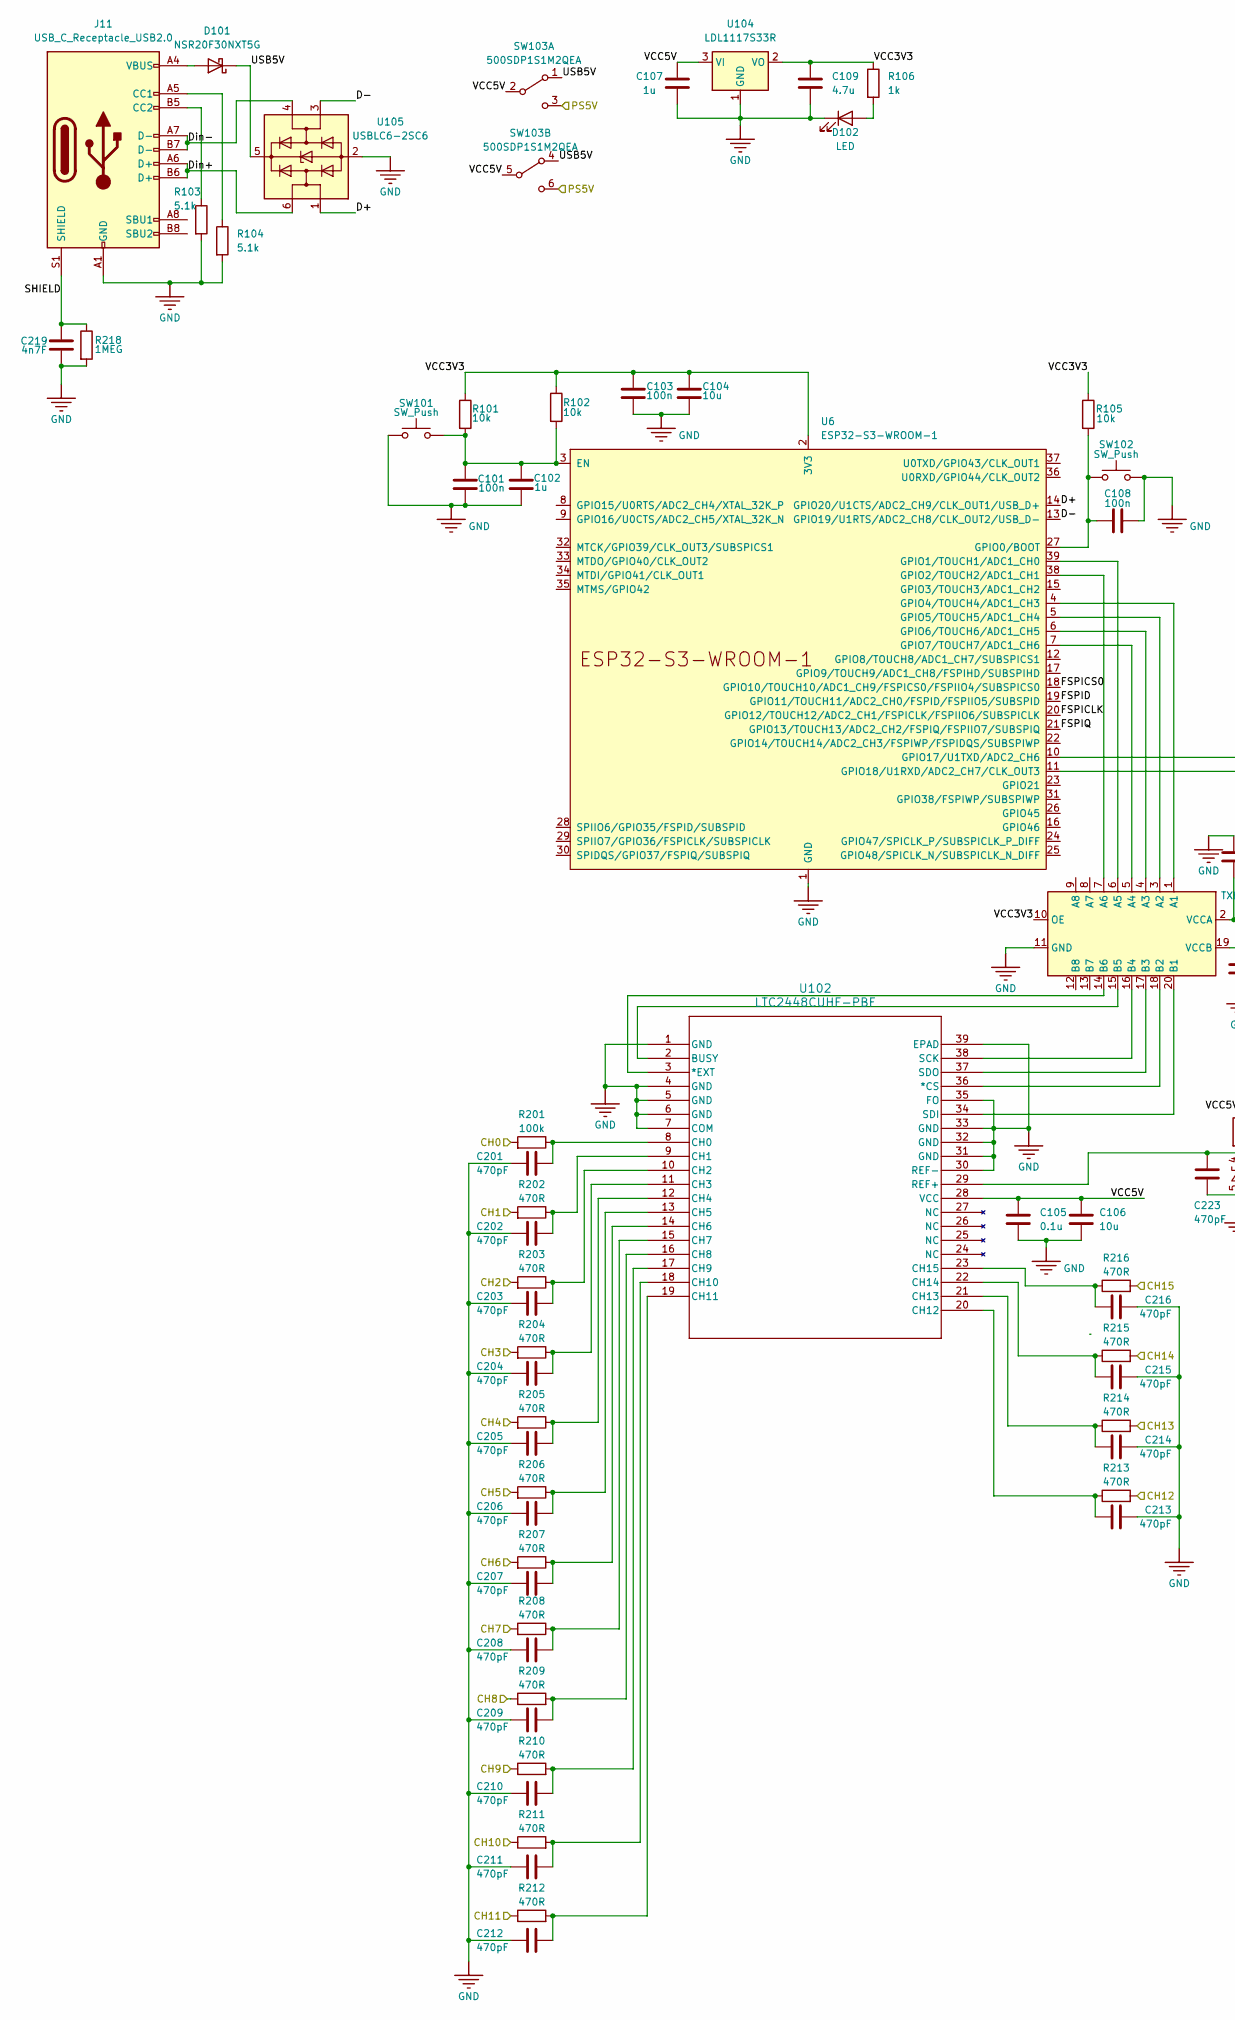
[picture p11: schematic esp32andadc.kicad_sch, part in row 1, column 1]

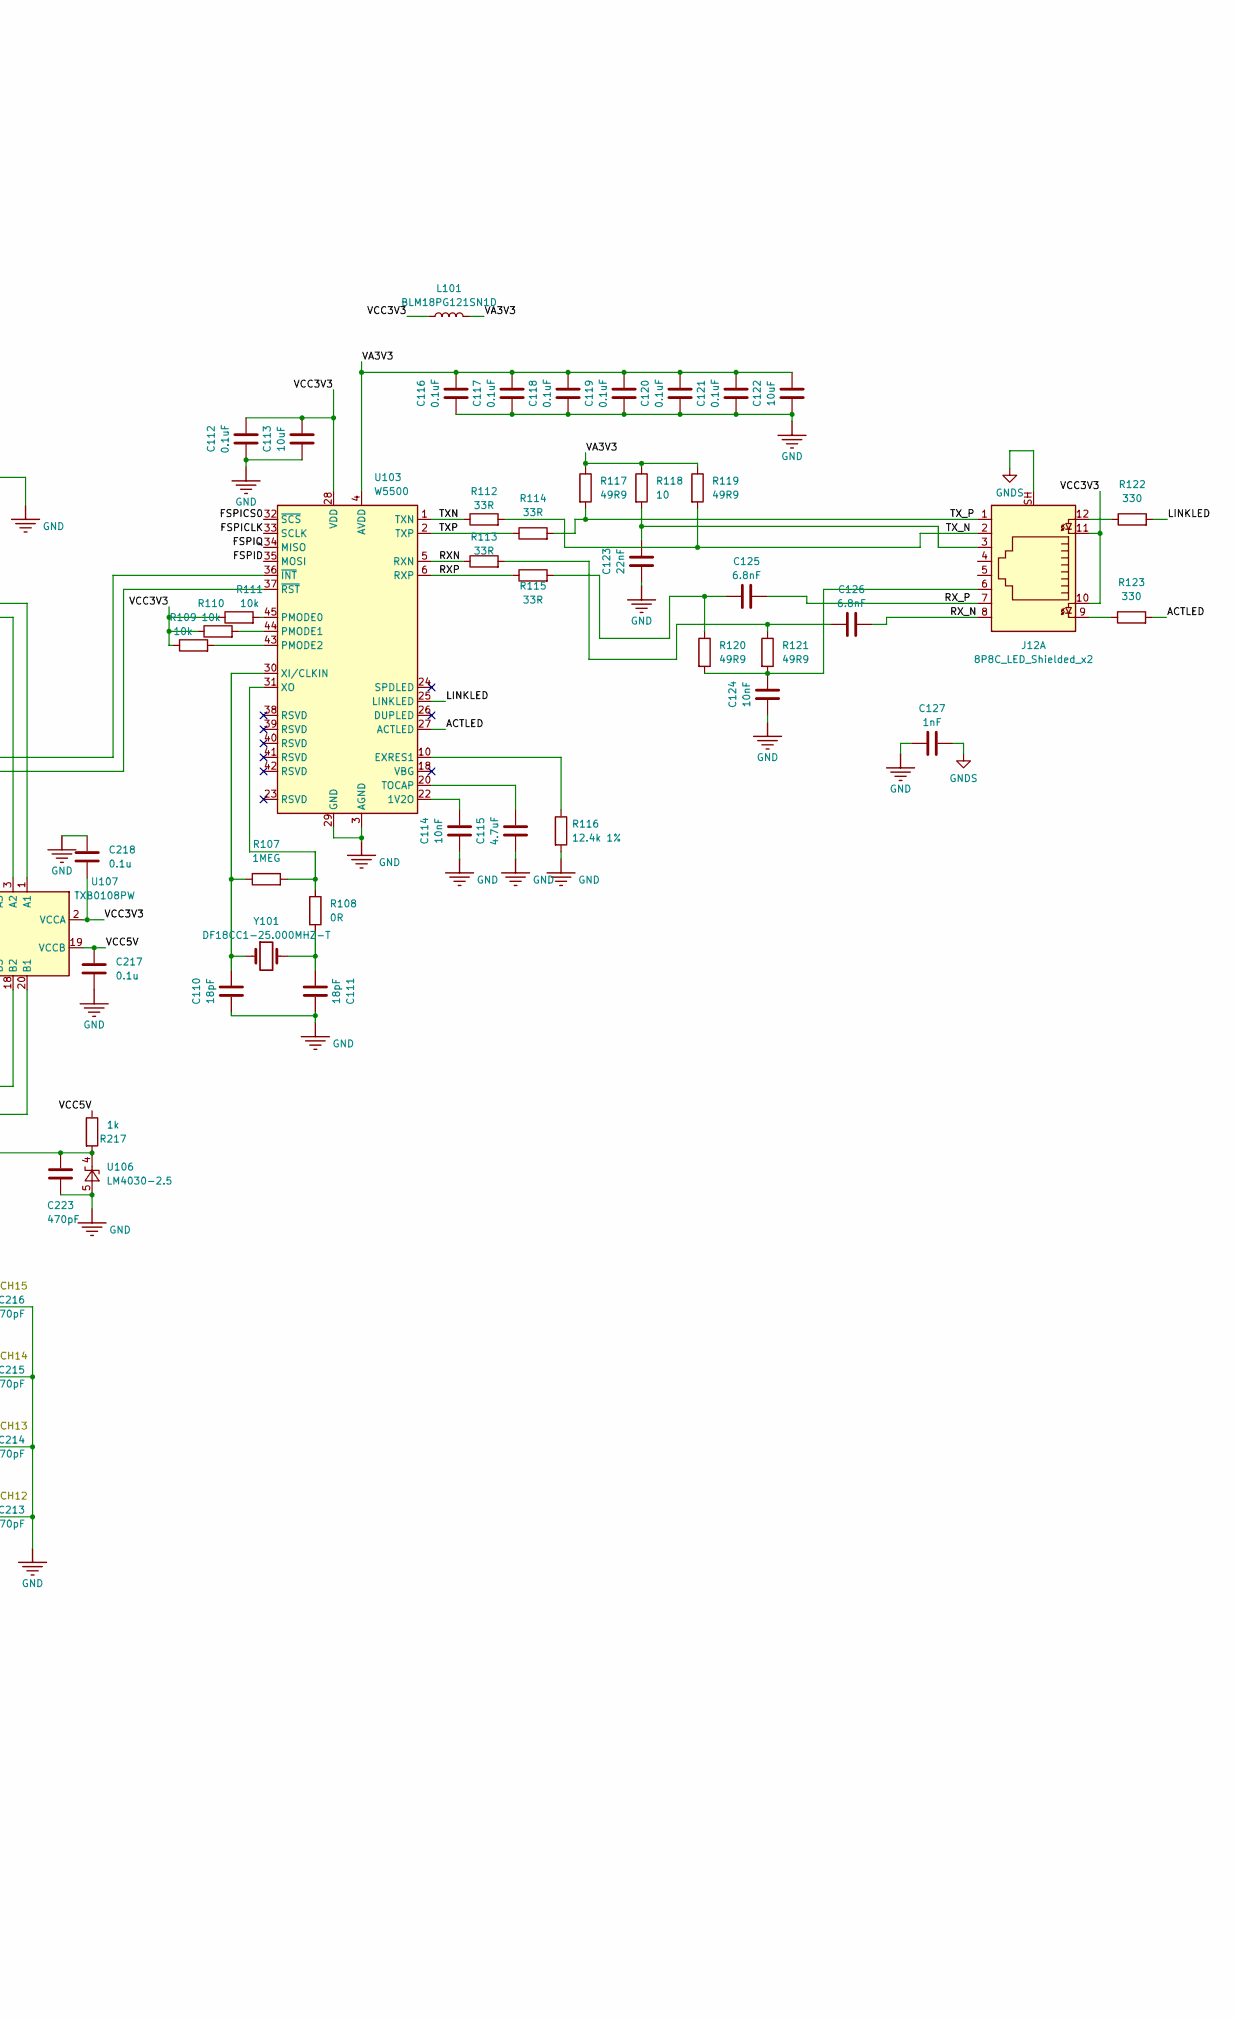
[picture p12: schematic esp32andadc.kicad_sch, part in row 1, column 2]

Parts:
C101, C103, C108: 100n; C_0603_1608Metric
C102, C107: 1u; C_0603_1608Metric
C104, C106: 10u; C_0603_1608Metric
C105, C217, C218: 0.1u; C_0603_1608Metric
C109: 4.7u; C_0603_1608Metric
C110, C111: 18pF; C_0603_1608Metric
C112, C116, C117, C118, C119, C120, C121: 0.1uF; C_0603_1608Metric
C113, C122: 10uF; C_0603_1608Metric
C114, C124: 10nF; C_0603_1608Metric
C115: 4.7uF; C_0603_1608Metric
C123: 22nF; C_0603_1608Metric
C125, C126: 6.8nF; C_0603_1608Metric
C127: 1nF; C_0603_1608Metric
C201, C202, C203, C204, C205, C206, C207, C208, C209, C210, C211, C212, C213, C214, C215, C216, C223: 470pF; C_0603_1608Metric
C219: 4n7F; C_0603_1608Metric
D101: NSR20F30NXT5G; D_0603_1608Metric
D102: LED; LED_0603_1608Metric
J11: USB_C_Receptacle_USB2.0; USB_C_Receptacle_GCT_USB4105-xx-A_16P_TopMnt_Horizontal
J12: 8P8C_LED_Shielded_x2; CONN12_5-2301994-8_TEC
L101: BLM18PG121SN1D; L_0603_1608Metric
R101, R102, R105, R109, R110, R111: 10k; R_0603_1608Metric
R103, R104: 5.1k; R_0603_1608Metric
R106, R217: 1k; R_0603_1608Metric
R107, R218: 1MEG; R_0603_1608Metric
R108: 0R; R_0603_1608Metric
R112, R113, R114, R115: 33R; R_0603_1608Metric
R116: 12.4k 1%; R_0603_1608Metric
R117, R119, R120, R121: 49R9; R_0603_1608Metric
R118: 10; R_0603_1608Metric
R122, R123: 330; R_0603_1608Metric
R201: 100k; R_0603_1608Metric
R202, R203, R204, R205, R206, R207, R208, R209, R210, R211, R212, R213, R214, R215, R216: 470R; R_0603_1608Metric
SW101, SW102: SW_Push; SW_Push_1P1T_NO_CK_KMR2
SW103: 500SDP1S1M2QEA; SW_PUSH_E-Switch_500SDP1S1M2QEA
U6: ESP32-S3-WROOM-1; ESP32-S3-WROOM-1U
U102: LTC2448CUHF-PBF; QFN-38-1EP_5x7mm_P0.5mm_EP3.15x5.15mm
U103: W5500; LQFP-48_7x7mm_P0.5mm
U104: LDL1117S33R; SOT-223-3_TabPin2
U105: USBLC6-2SC6; SOT-23-6
U106: LM4030-2.5; SOT-23-5
U107: TXB0108PW; TSSOP-20_4.4x6.5mm_P0.65mm
Y101: DF18CC1-25.000MHZ-T; Crystal_SMD_HC49-SD

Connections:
/PS5V: SW103.3 (C), SW103.6 (C); also elsewhere on the board
/esp32andadc/ACTLED: R123.2, U103.27 (ACTLED)
/esp32andadc/CH0: R201.2; also elsewhere on the board
/esp32andadc/CH1: R202.2; also elsewhere on the board
/esp32andadc/CH2: R203.2; also elsewhere on the board
/esp32andadc/CH3: R204.2; also elsewhere on the board
/esp32andadc/CH4: R205.2; also elsewhere on the board
/esp32andadc/CH5: R206.2; also elsewhere on the board
/esp32andadc/CH6: R207.2; also elsewhere on the board
/esp32andadc/CH7: R208.2; also elsewhere on the board
/esp32andadc/CH8: R209.1; also elsewhere on the board
/esp32andadc/CH9: R210.1; also elsewhere on the board
/esp32andadc/CH10: R211.1; also elsewhere on the board
/esp32andadc/CH11: R212.1; also elsewhere on the board
/esp32andadc/CH12: R213.2; also elsewhere on the board
/esp32andadc/CH13: R214.2; also elsewhere on the board
/esp32andadc/CH14: R215.2; also elsewhere on the board
/esp32andadc/CH15: R216.2; also elsewhere on the board
/esp32andadc/D+: U105.1 (I/O1); also elsewhere on the board
/esp32andadc/D-: U105.3 (I/O2); also elsewhere on the board
/esp32andadc/Din+: J11.A6 (D+), J11.B6 (D+), U105.6 (I/O1)
/esp32andadc/Din-: J11.A7 (D-), J11.B7 (D-), U105.4 (I/O2)
/esp32andadc/FSPICLK: U103.33 (SCLK); also elsewhere on the board
/esp32andadc/FSPICS0: U103.32 (~SCS); also elsewhere on the board
/esp32andadc/FSPID: U103.35 (MOSI); also elsewhere on the board
/esp32andadc/FSPIQ: U103.34 (MISO); also elsewhere on the board
/esp32andadc/LINKLED: R122.2, U103.25 (LINKLED)
/esp32andadc/RXN: R113.1, U103.5 (RXN)
/esp32andadc/RXP: R115.1, U103.6 (RXP)
/esp32andadc/RX_N: C126.2, J12.8
/esp32andadc/RX_P: C125.2, J12.7
/esp32andadc/SHIELD: C219.2, J11.S1 (SHIELD), R218.1
/esp32andadc/TXN: R112.1, U103.1 (TXN)
/esp32andadc/TXP: R114.1, U103.2 (TXP)
/esp32andadc/TX_N: J12.2, R112.2, R119.2
/esp32andadc/TX_P: J12.1, R114.2, R117.2
/esp32andadc/USB5V: D101.1 (K), SW103.1 (A), SW103.4 (A), U105.5 (VBUS)
/esp32andadc/VA3V3: C116.2, C117.2, C118.2, C119.2, C120.2, C121.2, C122.2, L101.2, R117.1, R118.1, R119.1, U103.4 (AVDD), U103.8 (AVDD), U103.11 (AVDD), U103.15 (AVDD), U103.17 (AVDD), U103.21 (AVDD)
/esp32andadc/VCC3V3: C103.1, C104.1, C109.1, C112.2, C113.2, C218.2, J12.10, J12.11, L101.1, R101.1, R102.1, R105.1, R106.1, R109.1, R110.1, R111.1, U103.28 (VDD), U104.2 (VO), U107.2 (VCCA), U107.10 (OE); also elsewhere on the board
/esp32andadc/VCC5V: C105.1, C106.1, C107.1, C217.1, R217.1, SW103.2 (B), SW103.5 (B), U102.28 (VCC), U104.3 (VI), U107.19 (VCCB)
GND: C101.2, C102.2, C103.2, C104.2, C105.2, C106.2, C107.2, C108.2, C109.2, C110.1, C111.2, C112.1, C113.1, C114.1, C115.1, C116.1, C117.1, C118.1, C119.1, C120.1, C121.1, C122.1, C123.1, C124.1, C127.1, C201.2, C202.2, C203.2, C204.2, C205.2, C206.2, C207.2, C208.2, C209.2, C210.2, C211.2, C212.2, C213.2, C214.2, C215.2, C216.2, C217.2, C218.1, C219.1, C223.2, D102.1 (K), J11.A1 (GND), J11.A12 (GND), J11.B1 (GND), J11.B12 (GND), R103.2, R104.2, R116.2, R218.2, SW101.1, SW102.2, U102.1 (GND), U102.4 (GND), U102.5 (GND), U102.6 (GND), U102.7 (COM), U102.30 (REF-), U102.31 (GND), U102.32 (GND), U102.33 (GND), U102.35 (FO), U102.39 (EPAD), U103.3 (AGND), U103.9 (AGND), U103.14 (AGND), U103.16 (AGND), U103.19 (AGND), U103.29 (GND), U103.48 (AGND), U104.1 (GND), U105.2 (GND), U106.5 (A), U107.11 (GND); also elsewhere on the board
GNDS: C127.2, J12.SH
unnamed: C111.1, R108.2, Y101.2
unnamed: C123.2, J12.3, R118.2
unnamed: C124.2, J12.6, R120.2, R121.2
unnamed: C125.1, R115.2, R120.1
unnamed: C126.1, R113.2, R121.1
unnamed: D101.2 (A), J11.A4 (VBUS), J11.A9 (VBUS), J11.B4 (VBUS), J11.B9 (VBUS)
unnamed: D102.2 (A), R106.2
unnamed: J11.A5 (CC1), R104.1
unnamed: J11.B5 (CC2), R103.1
unnamed: J12.9, R123.1
unnamed: J12.12, R122.1
unnamed 252: C101.1, C102.1, R101.2, R102.2, SW101.2; also elsewhere on the board
unnamed 253: C108.1, R105.2, SW102.1; also elsewhere on the board
unnamed 254: U107.6 (A5); also elsewhere on the board
unnamed 255: U107.7 (A6); also elsewhere on the board
unnamed 256: U107.1 (A1); also elsewhere on the board
unnamed 257: U107.3 (A2); also elsewhere on the board
unnamed 258: U107.4 (A3); also elsewhere on the board
unnamed 259: U107.5 (A4); also elsewhere on the board
unnamed 260: U103.36 (~INT); also elsewhere on the board
unnamed 261: U103.37 (~RST); also elsewhere on the board
unnamed: U102.36 (*CS), U107.18 (B2)
unnamed: U102.3 (*EXT), U107.14 (B6)
unnamed: U102.2 (BUSY), U107.15 (B5)
unnamed: C201.1, R201.1, U102.8 (CH0)
unnamed: C202.1, R202.1, U102.9 (CH1)
unnamed: C203.1, R203.1, U102.10 (CH2)
unnamed: C204.1, R204.1, U102.11 (CH3)
unnamed: C205.1, R205.1, U102.12 (CH4)
unnamed: C206.1, R206.1, U102.13 (CH5)
unnamed: C207.1, R207.1, U102.14 (CH6)
unnamed: C208.1, R208.1, U102.15 (CH7)
unnamed: C209.1, R209.2, U102.16 (CH8)
unnamed: C210.1, R210.2, U102.17 (CH9)
unnamed: C211.1, R211.2, U102.18 (CH10)
unnamed: C212.1, R212.2, U102.19 (CH11)
unnamed: C213.1, R213.1, U102.20 (CH12)
unnamed: C214.1, R214.1, U102.21 (CH13)
unnamed: C215.1, R215.1, U102.22 (CH14)
unnamed: C216.1, R216.1, U102.23 (CH15)
unnamed: C223.1, R217.2, U102.29 (REF+), U106.4 (K)
unnamed: U102.38 (SCK), U107.16 (B4)
unnamed: U102.34 (SDI), U107.20 (B1)
unnamed: U102.37 (SDO), U107.17 (B3)
unnamed: C114.2, U103.22 (1V2O)
unnamed: R116.1, U103.10 (EXRES1)
unnamed: R111.2, U103.45 (PMODE0)
unnamed: R110.2, U103.44 (PMODE1)
unnamed: R109.2, U103.43 (PMODE2)
unnamed: C115.2, U103.20 (TOCAP)
unnamed: C110.2, R107.1, U103.30 (XI/CLKIN), Y101.1
unnamed: R107.2, R108.1, U103.31 (XO)

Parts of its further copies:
U101: ESP32-S3-WROOM-1; ESP32-S3-WROOM-1U

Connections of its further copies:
/esp32andadc/D+: U101.14 (GPIO20/U1CTS/ADC2_CH9/CLK_OUT1/USB_D+); also elsewhere on the board
/esp32andadc/D-: U101.13 (GPIO19/U1RTS/ADC2_CH8/CLK_OUT2/USB_D-); also elsewhere on the board
/esp32andadc/FSPICLK: U101.20 (GPIO12/TOUCH12/ADC2_CH1/FSPICLK/FSPIIO6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); also elsewhere on the board
/esp32andadc/FSPICS0: U101.18 (GPIO10/TOUCH10/ADC1_CH9/FSPICS0/FSPIIO4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); also elsewhere on the board
/esp32andadc/FSPID: U101.19 (GPIO11/TOUCH11/ADC2_CH0/FSPID/FSPIIO5/S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); also elsewhere on the board
/esp32andadc/FSPIQ: U101.21 (GPIO13/TOUCH13/ADC2_CH2/FSPIQ/FSPIIO7/S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); also elsewhere on the board
/esp32andadc/VCC3V3: U101.2 (3V3); also elsewhere on the board
GND: U101.1 (GND), U101.40 (GND), U101.41 (GND); also elsewhere on the board
unnamed 252: U101.3 (EN); also elsewhere on the board
unnamed 253: U101.27 (GPIO0/BOOT); also elsewhere on the board
unnamed 254: U101.39 (GPIO1/TOUCH1/ADC1_CH0); also elsewhere on the board
unnamed 255: U101.38 (GPIO2/TOUCH2/ADC1_CH1); also elsewhere on the board
unnamed 256: U101.4 (GPIO4/TOUCH4/ADC1_CH3); also elsewhere on the board
unnamed 257: U101.5 (GPIO5/TOUCH5/ADC1_CH4); also elsewhere on the board
unnamed 258: U101.6 (GPIO6/TOUCH6/ADC1_CH5); also elsewhere on the board
unnamed 259: U101.7 (GPIO7/TOUCH7/ADC1_CH6); also elsewhere on the board
unnamed 260: U101.10 (GPIO17/U1TXD/ADC2_CH6); also elsewhere on the board
unnamed 261: U101.11 (GPIO18/U1RXD/ADC2_CH7/CLK_OUT3); also elsewhere on the board

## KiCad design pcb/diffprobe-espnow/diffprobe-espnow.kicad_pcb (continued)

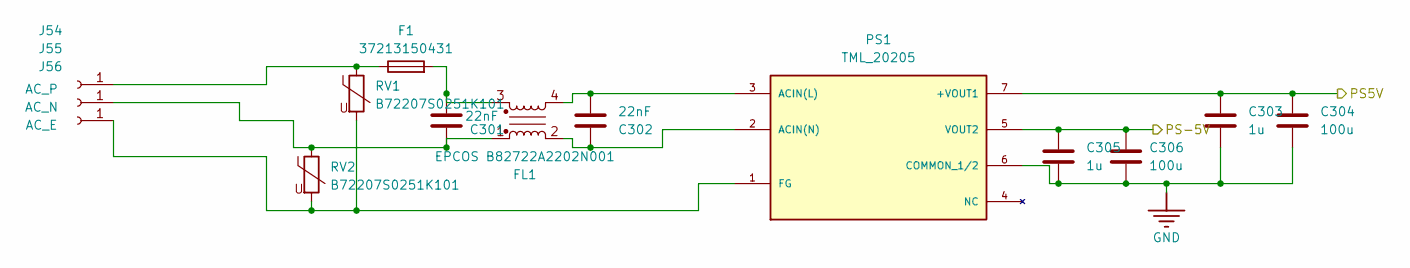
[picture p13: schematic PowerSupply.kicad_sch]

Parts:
C301, C302: 22nF; C_Rect_L13.0mm_W4.0mm_P10.00mm_FKS3_FKP3_MKS4
C303, C305: 1u; C_0603_1608Metric
C304, C306: 100u; CP_Elec_10x12.5
F1: 37213150431; Fuse_Littelfuse_372_D8.50mm
FL1: EPCOS B82722A2202N001; Choke_EPCOS_B82722A
J54: AC_P; Pin_D1.4mm_L8.5mm_W2.8mm_FlatFork
J55: AC_N; Pin_D1.4mm_L8.5mm_W2.8mm_FlatFork
J56: AC_E; Pin_D1.4mm_L8.5mm_W2.8mm_FlatFork
PS1: TML_20205; CONV_TML_20205; PARTREV April 7,2021
RV1, RV2: B72207S0251K101; RV_Disc_D9mm_W4.2mm_P5mm

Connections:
/PS5V: C303.1, C304.1, PS1.7 (+VOUT1); also elsewhere on the board
/PS-5V: C305.1, C306.1, PS1.5 (VOUT2); also elsewhere on the board
GND: C303.2, C304.2, C305.2, C306.2, PS1.6 (COMMON_1/2); also elsewhere on the board
unnamed: C301.2, F1.2, FL1.3
unnamed: F1.1, J54.1, RV1.1
unnamed: C301.1, FL1.1, J55.1, RV2.1
unnamed: J56.1, PS1.1 (FG), RV1.2, RV2.2
unnamed: C302.2, FL1.4, PS1.3 (ACIN(L))
unnamed: C302.1, FL1.2, PS1.2 (ACIN(N))

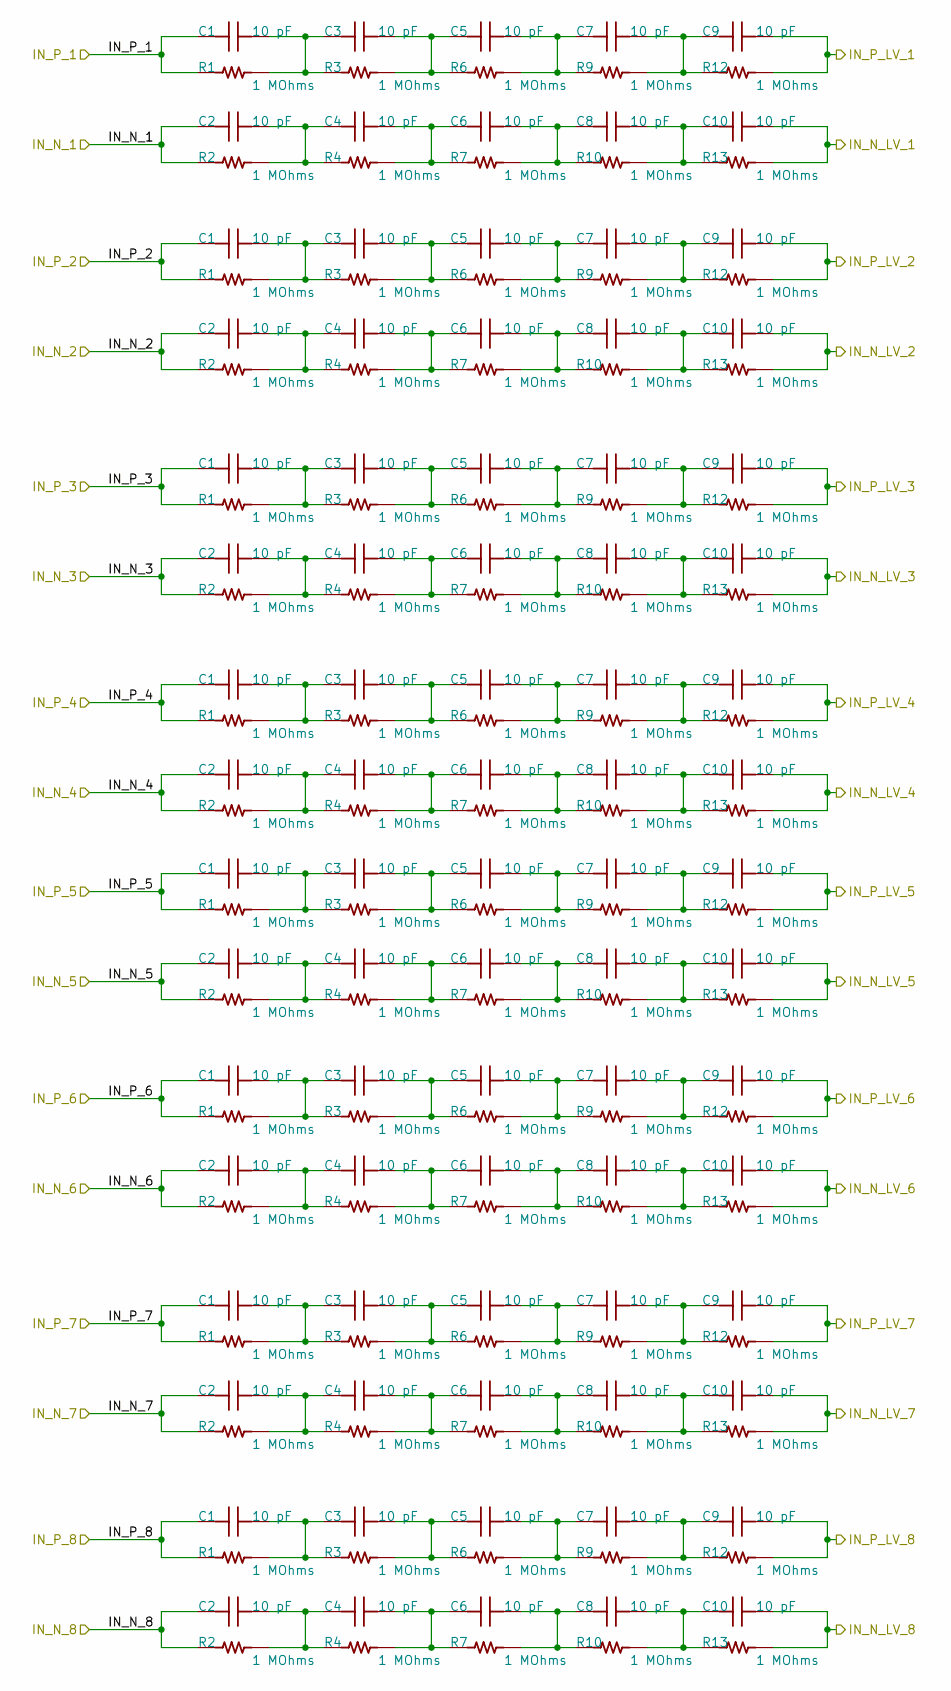
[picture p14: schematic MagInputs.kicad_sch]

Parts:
C1, C2, C3, C4, C5, C6, C7, C8, C9, C10: 10 pF; C_1206_3216Metric; TOLERANCE ±5%; VOLTAGE - RATED 500V; PART NUMBER CC1206JRNPOBBN100
R1, R2, R3, R4, R6, R7, R9, R10, R12, R13: 1 MOhms; R_1206_3216Metric; RATINGS AEC-Q200; TOLERANCE ±0.1%; PART NUMBER RNCS1206BKE1M00

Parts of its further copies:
C501, C502, C503, C504, C505, C506, C507, C508, C509, C510, C511, C512, C513, C514, C515, C516, C517, C518, C519, C520, C521, C522, C523, C524, C525, C526, C527, C528, C529, C530, C531, C532, C533, C534, C535, C536, C537, C538, C539, C540, C541, C542, C543, C544, C545, C546, C547, C548, C549, C550, C551, C552, C553, C554, C555, C556, C557, C558, C559, C560, C561, C562, C563, C564, C565, C566, C567, C568, C569, C570, C571, C572, C573, C574, C575, C576, C577, C578, C579, C580, C581, C582, C583, C584, C585, C586, C587, C588, C589, C590, C591, C592, C593, C594, C595, C596, C597, C598, C599, C600, C601, C602, C603, C604, C605, C606, C607, C608, C609, C610, C611, C612, C613, C614, C615, C616, C617, C618, C619, C620, C621, C622, C623, C624, C625, C626, C627, C628, C629, C630, C631, C632, C633, C634, C635, C636, C637, C638, C639, C640, C641, C642, C643, C644, C645, C646, C647, C648, C649, C650, C651, C652, C653, C654, C655, C656, C657, C658, C659, C660: 10 pF; C_1206_3216Metric; TOLERANCE ±5%; VOLTAGE - RATED 500V; PART NUMBER CC1206JRNPOBBN100
R501, R502, R503, R504, R505, R506, R507, R508, R509, R510, R511, R512, R513, R514, R515, R516, R517, R518, R519, R520, R521, R522, R523, R524, R525, R526, R527, R528, R529, R530, R531, R532, R533, R534, R535, R536, R537, R538, R539, R540, R541, R542, R543, R544, R545, R546, R547, R548, R549, R550, R551, R552, R553, R554, R555, R556, R557, R558, R559, R560, R561, R562, R563, R564, R565, R566, R567, R568, R569, R570, R571, R572, R573, R574, R575, R576, R577, R578, R579, R580, R581, R582, R583, R584, R585, R586, R587, R588, R589, R590, R591, R592, R593, R594, R595, R596, R597, R598, R599, R600, R601, R602, R603, R604, R605, R606, R607, R608, R609, R610, R611, R612, R613, R614, R615, R616, R617, R618, R619, R620, R621, R622, R623, R624, R625, R626, R627, R628, R629, R630, R631, R632, R633, R634, R635, R636, R637, R638, R639, R640, R641, R642, R643, R644, R645, R646, R647, R648, R649, R650, R651, R652, R653, R654, R655, R656, R657, R658, R659, R660: 1 MOhms; R_1206_3216Metric; RATINGS AEC-Q200; TOLERANCE ±0.1%; PART NUMBER RNCS1206BKE1M00

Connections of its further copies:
/8diffInputs1/IN_N_1: C586.1, R586.1; also elsewhere on the board
/8diffInputs1/IN_N_2: C596.1, R596.1; also elsewhere on the board
/8diffInputs1/IN_N_3: C606.1, R606.1; also elsewhere on the board
/8diffInputs1/IN_N_4: C616.1, R616.1; also elsewhere on the board
/8diffInputs1/IN_N_5: C626.1, R626.1; also elsewhere on the board
/8diffInputs1/IN_N_6: C636.1, R636.1; also elsewhere on the board
/8diffInputs1/IN_N_7: C646.1, R646.1; also elsewhere on the board
/8diffInputs1/IN_N_8: C656.1, R656.1; also elsewhere on the board
/8diffInputs1/IN_N_LV_1: C590.2, R590.2; also elsewhere on the board
/8diffInputs1/IN_N_LV_2: C600.2, R600.2; also elsewhere on the board
/8diffInputs1/IN_N_LV_3: C610.2, R610.2; also elsewhere on the board
/8diffInputs1/IN_N_LV_4: C620.2, R620.2; also elsewhere on the board
/8diffInputs1/IN_N_LV_5: C630.2, R630.2; also elsewhere on the board
/8diffInputs1/IN_N_LV_6: C640.2, R640.2; also elsewhere on the board
/8diffInputs1/IN_N_LV_7: C650.2, R650.2; also elsewhere on the board
/8diffInputs1/IN_N_LV_8: C660.2, R660.2; also elsewhere on the board
/8diffInputs1/IN_P_1: C581.1, R581.1; also elsewhere on the board
/8diffInputs1/IN_P_2: C591.1, R591.1; also elsewhere on the board
/8diffInputs1/IN_P_3: C601.1, R601.1; also elsewhere on the board
/8diffInputs1/IN_P_4: C611.1, R611.1; also elsewhere on the board
/8diffInputs1/IN_P_5: C621.1, R621.1; also elsewhere on the board
/8diffInputs1/IN_P_6: C631.1, R631.1; also elsewhere on the board
/8diffInputs1/IN_P_7: C641.1, R641.1; also elsewhere on the board
/8diffInputs1/IN_P_8: C651.1, R651.1; also elsewhere on the board
/8diffInputs1/IN_P_LV_1: C585.2, R585.2; also elsewhere on the board
/8diffInputs1/IN_P_LV_2: C595.2, R595.2; also elsewhere on the board
/8diffInputs1/IN_P_LV_3: C605.2, R605.2; also elsewhere on the board
/8diffInputs1/IN_P_LV_4: C615.2, R615.2; also elsewhere on the board
/8diffInputs1/IN_P_LV_5: C625.2, R625.2; also elsewhere on the board
/8diffInputs1/IN_P_LV_6: C635.2, R635.2; also elsewhere on the board
/8diffInputs1/IN_P_LV_7: C645.2, R645.2; also elsewhere on the board
/8diffInputs1/IN_P_LV_8: C655.2, R655.2; also elsewhere on the board
/8diffInputs/IN_N_1: C506.1, R506.1; also elsewhere on the board
/8diffInputs/IN_N_2: C516.1, R516.1; also elsewhere on the board
/8diffInputs/IN_N_3: C526.1, R526.1; also elsewhere on the board
/8diffInputs/IN_N_4: C536.1, R536.1; also elsewhere on the board
/8diffInputs/IN_N_5: C546.1, R546.1; also elsewhere on the board
/8diffInputs/IN_N_6: C556.1, R556.1; also elsewhere on the board
/8diffInputs/IN_N_7: C566.1, R566.1; also elsewhere on the board
/8diffInputs/IN_N_8: C576.1, R576.1; also elsewhere on the board
/8diffInputs/IN_N_LV_1: C510.2, R510.2; also elsewhere on the board
/8diffInputs/IN_N_LV_2: C520.2, R520.2; also elsewhere on the board
/8diffInputs/IN_N_LV_3: C530.2, R530.2; also elsewhere on the board
/8diffInputs/IN_N_LV_4: C540.2, R540.2; also elsewhere on the board
/8diffInputs/IN_N_LV_5: C550.2, R550.2; also elsewhere on the board
/8diffInputs/IN_N_LV_6: C560.2, R560.2; also elsewhere on the board
/8diffInputs/IN_N_LV_7: C570.2, R570.2; also elsewhere on the board
/8diffInputs/IN_N_LV_8: C580.2, R580.2; also elsewhere on the board
/8diffInputs/IN_P_1: C501.1, R501.1; also elsewhere on the board
/8diffInputs/IN_P_2: C511.1, R511.1; also elsewhere on the board
/8diffInputs/IN_P_3: C521.1, R521.1; also elsewhere on the board
/8diffInputs/IN_P_4: C531.1, R531.1; also elsewhere on the board
/8diffInputs/IN_P_5: C541.1, R541.1; also elsewhere on the board
/8diffInputs/IN_P_6: C551.1, R551.1; also elsewhere on the board
/8diffInputs/IN_P_7: C561.1, R561.1; also elsewhere on the board
/8diffInputs/IN_P_8: C571.1, R571.1; also elsewhere on the board
/8diffInputs/IN_P_LV_1: C505.2, R505.2; also elsewhere on the board
/8diffInputs/IN_P_LV_2: C515.2, R515.2; also elsewhere on the board
/8diffInputs/IN_P_LV_3: C525.2, R525.2; also elsewhere on the board
/8diffInputs/IN_P_LV_4: C535.2, R535.2; also elsewhere on the board
/8diffInputs/IN_P_LV_5: C545.2, R545.2; also elsewhere on the board
/8diffInputs/IN_P_LV_6: C555.2, R555.2; also elsewhere on the board
/8diffInputs/IN_P_LV_7: C565.2, R565.2; also elsewhere on the board
/8diffInputs/IN_P_LV_8: C575.2, R575.2; also elsewhere on the board
unnamed: C501.2, C502.1, R501.2, R502.1
unnamed: C502.2, C503.1, R502.2, R503.1
unnamed: C503.2, C504.1, R503.2, R504.1
unnamed: C504.2, C505.1, R504.2, R505.1
unnamed: C506.2, C507.1, R506.2, R507.1
unnamed: C507.2, C508.1, R507.2, R508.1
unnamed: C508.2, C509.1, R508.2, R509.1
unnamed: C509.2, C510.1, R509.2, R510.1
unnamed: C511.2, C512.1, R511.2, R512.1
unnamed: C512.2, C513.1, R512.2, R513.1
unnamed: C513.2, C514.1, R513.2, R514.1
unnamed: C514.2, C515.1, R514.2, R515.1
unnamed: C516.2, C517.1, R516.2, R517.1
unnamed: C517.2, C518.1, R517.2, R518.1
unnamed: C518.2, C519.1, R518.2, R519.1
unnamed: C519.2, C520.1, R519.2, R520.1
unnamed: C521.2, C522.1, R521.2, R522.1
unnamed: C522.2, C523.1, R522.2, R523.1
unnamed: C523.2, C524.1, R523.2, R524.1
unnamed: C524.2, C525.1, R524.2, R525.1
unnamed: C526.2, C527.1, R526.2, R527.1
unnamed: C527.2, C528.1, R527.2, R528.1
unnamed: C528.2, C529.1, R528.2, R529.1
unnamed: C529.2, C530.1, R529.2, R530.1
unnamed: C531.2, C532.1, R531.2, R532.1
unnamed: C532.2, C533.1, R532.2, R533.1
unnamed: C533.2, C534.1, R533.2, R534.1
unnamed: C534.2, C535.1, R534.2, R535.1
unnamed: C536.2, C537.1, R536.2, R537.1
unnamed: C537.2, C538.1, R537.2, R538.1
unnamed: C538.2, C539.1, R538.2, R539.1
unnamed: C539.2, C540.1, R539.2, R540.1
unnamed: C541.2, C542.1, R541.2, R542.1
unnamed: C542.2, C543.1, R542.2, R543.1
unnamed: C543.2, C544.1, R543.2, R544.1
unnamed: C544.2, C545.1, R544.2, R545.1
unnamed: C546.2, C547.1, R546.2, R547.1
unnamed: C547.2, C548.1, R547.2, R548.1
unnamed: C548.2, C549.1, R548.2, R549.1
unnamed: C549.2, C550.1, R549.2, R550.1
unnamed: C551.2, C552.1, R551.2, R552.1
unnamed: C552.2, C553.1, R552.2, R553.1
unnamed: C553.2, C554.1, R553.2, R554.1
unnamed: C554.2, C555.1, R554.2, R555.1
unnamed: C556.2, C557.1, R556.2, R557.1
unnamed: C557.2, C558.1, R557.2, R558.1
unnamed: C558.2, C559.1, R558.2, R559.1
unnamed: C559.2, C560.1, R559.2, R560.1
unnamed: C561.2, C562.1, R561.2, R562.1
unnamed: C562.2, C563.1, R562.2, R563.1
unnamed: C563.2, C564.1, R563.2, R564.1
unnamed: C564.2, C565.1, R564.2, R565.1
unnamed: C566.2, C567.1, R566.2, R567.1
unnamed: C567.2, C568.1, R567.2, R568.1
unnamed: C568.2, C569.1, R568.2, R569.1
unnamed: C569.2, C570.1, R569.2, R570.1
unnamed: C571.2, C572.1, R571.2, R572.1
unnamed: C572.2, C573.1, R572.2, R573.1
unnamed: C573.2, C574.1, R573.2, R574.1
unnamed: C574.2, C575.1, R574.2, R575.1
unnamed: C576.2, C577.1, R576.2, R577.1
unnamed: C577.2, C578.1, R577.2, R578.1
unnamed: C578.2, C579.1, R578.2, R579.1
unnamed: C579.2, C580.1, R579.2, R580.1
unnamed: C581.2, C582.1, R581.2, R582.1
unnamed: C582.2, C583.1, R582.2, R583.1
unnamed: C583.2, C584.1, R583.2, R584.1
unnamed: C584.2, C585.1, R584.2, R585.1
unnamed: C586.2, C587.1, R586.2, R587.1
unnamed: C587.2, C588.1, R587.2, R588.1
unnamed: C588.2, C589.1, R588.2, R589.1
unnamed: C589.2, C590.1, R589.2, R590.1
unnamed: C591.2, C592.1, R591.2, R592.1
unnamed: C592.2, C593.1, R592.2, R593.1
unnamed: C593.2, C594.1, R593.2, R594.1
unnamed: C594.2, C595.1, R594.2, R595.1
unnamed: C596.2, C597.1, R596.2, R597.1
unnamed: C597.2, C598.1, R597.2, R598.1
unnamed: C598.2, C599.1, R598.2, R599.1
unnamed: C599.2, C600.1, R599.2, R600.1
unnamed: C601.2, C602.1, R601.2, R602.1
unnamed: C602.2, C603.1, R602.2, R603.1
unnamed: C603.2, C604.1, R603.2, R604.1
unnamed: C604.2, C605.1, R604.2, R605.1
unnamed: C606.2, C607.1, R606.2, R607.1
unnamed: C607.2, C608.1, R607.2, R608.1
unnamed: C608.2, C609.1, R608.2, R609.1
unnamed: C609.2, C610.1, R609.2, R610.1
unnamed: C611.2, C612.1, R611.2, R612.1
unnamed: C612.2, C613.1, R612.2, R613.1
unnamed: C613.2, C614.1, R613.2, R614.1
unnamed: C614.2, C615.1, R614.2, R615.1
unnamed: C616.2, C617.1, R616.2, R617.1
unnamed: C617.2, C618.1, R617.2, R618.1
unnamed: C618.2, C619.1, R618.2, R619.1
unnamed: C619.2, C620.1, R619.2, R620.1
unnamed: C621.2, C622.1, R621.2, R622.1
unnamed: C622.2, C623.1, R622.2, R623.1
unnamed: C623.2, C624.1, R623.2, R624.1
unnamed: C624.2, C625.1, R624.2, R625.1
unnamed: C626.2, C627.1, R626.2, R627.1
unnamed: C627.2, C628.1, R627.2, R628.1
unnamed: C628.2, C629.1, R628.2, R629.1
unnamed: C629.2, C630.1, R629.2, R630.1
unnamed: C631.2, C632.1, R631.2, R632.1
unnamed: C632.2, C633.1, R632.2, R633.1
unnamed: C633.2, C634.1, R633.2, R634.1
unnamed: C634.2, C635.1, R634.2, R635.1
unnamed: C636.2, C637.1, R636.2, R637.1
unnamed: C637.2, C638.1, R637.2, R638.1
unnamed: C638.2, C639.1, R638.2, R639.1
unnamed: C639.2, C640.1, R639.2, R640.1
unnamed: C641.2, C642.1, R641.2, R642.1
unnamed: C642.2, C643.1, R642.2, R643.1
unnamed: C643.2, C644.1, R643.2, R644.1
unnamed: C644.2, C645.1, R644.2, R645.1
unnamed: C646.2, C647.1, R646.2, R647.1
unnamed: C647.2, C648.1, R647.2, R648.1
unnamed: C648.2, C649.1, R648.2, R649.1
unnamed: C649.2, C650.1, R649.2, R650.1
unnamed: C651.2, C652.1, R651.2, R652.1
unnamed: C652.2, C653.1, R652.2, R653.1
unnamed: C653.2, C654.1, R653.2, R654.1
unnamed: C654.2, C655.1, R654.2, R655.1
unnamed: C656.2, C657.1, R656.2, R657.1
unnamed: C657.2, C658.1, R657.2, R658.1
unnamed: C658.2, C659.1, R658.2, R659.1
unnamed: C659.2, C660.1, R659.2, R660.1

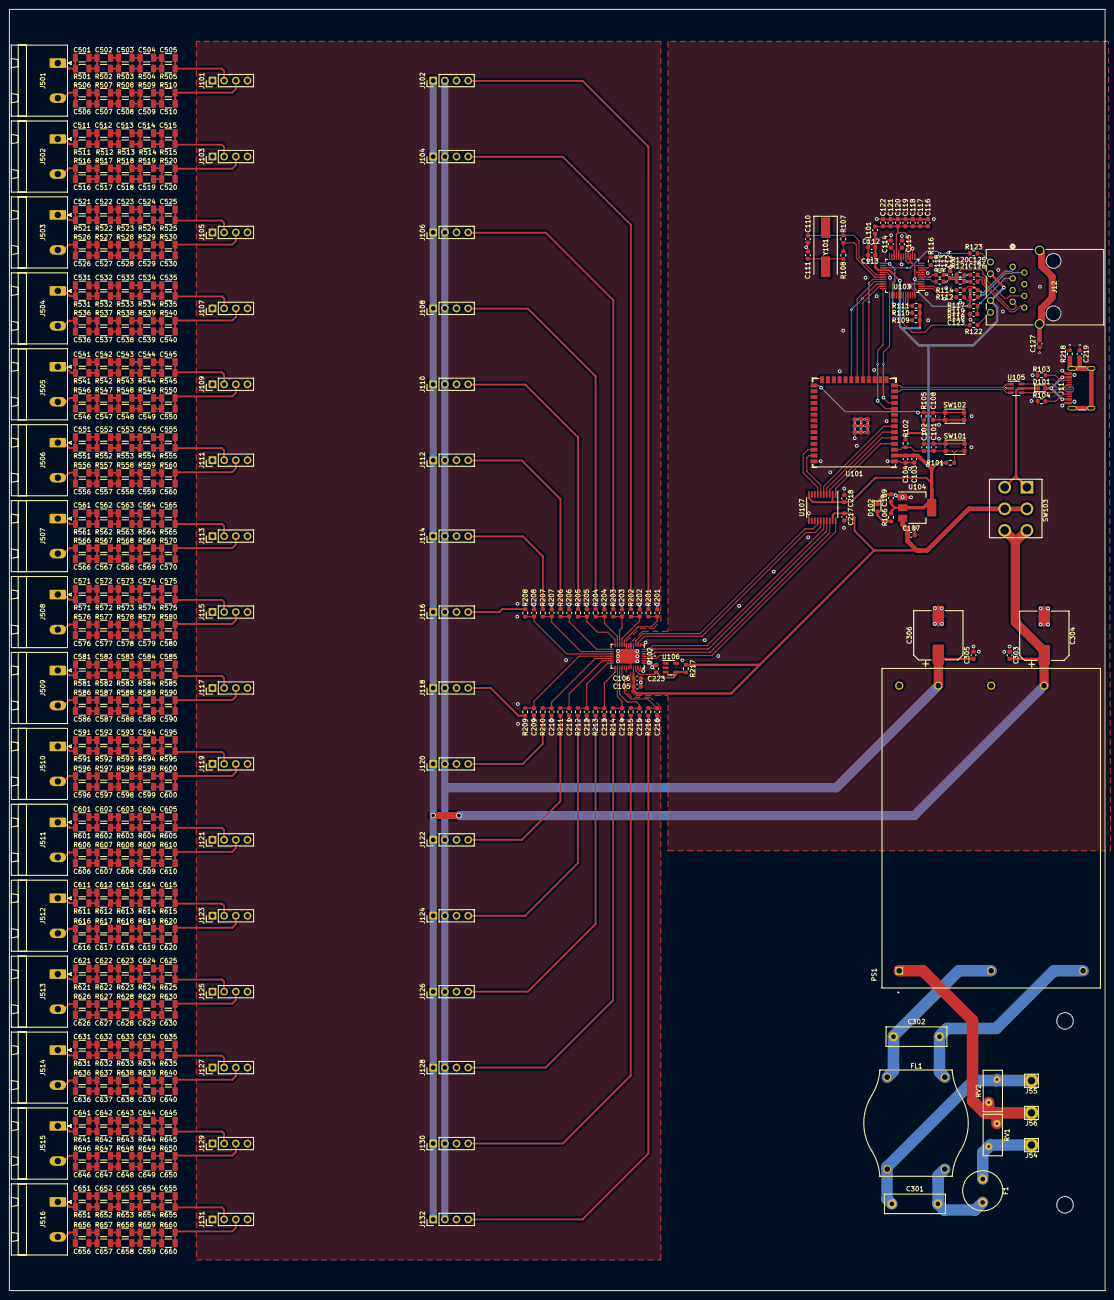
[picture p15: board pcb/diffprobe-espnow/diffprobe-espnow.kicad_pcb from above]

Board: 2 copper layers, 238.2 x 278.6 mm, 486 parts (0 on the bottom side), 293 nets.

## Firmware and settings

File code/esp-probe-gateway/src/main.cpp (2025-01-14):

#include "Arduino.h"
#include <SPI.h>
#include "LTC2449.h"
#include <Ethernet.h>
#include <esp_task_wdt.h>
#include <esp_now.h>
#include <WiFi.h>
#include <esp_wifi.h>
#include <ArduinoJSON.h>

#define SPI2_MOSI 11
#define SPI2_CS 10
#define SPI2_MISO 13
#define SPI2_CLK 12
#define W5500_INT 17
#define W5500_RST 18

#define SPI3_MOSI 4
#define SPI3_CS 5
#define SPI3_MISO 6
#define SPI3_CLK 7
#define LTC2449_CS SPI3_CS
#define ADC_BUSY_PIN 1
#define ADC_EXT_CLK_PIN 2

#if CONFIG_IDF_TARGET_ESP32S2 || CONFIG_IDF_TARGET_ESP32S3
#define VSPI FSPI
#endif

// #define DEBUG

// fspi = spi2 = SPI = w5500
// hspi = spi3 = ltc2448

// Enter a MAC address and IP address for your controller below.
// The IP address will be dependent on your local network:
byte mac[] = {
    0xDE, 0xAD, 0xBE, 0xEF, 0xFE, 0xED};
static RTC_NOINIT_ATTR uint8_t ip_addr1;
static RTC_NOINIT_ATTR uint8_t ip_addr2;
static RTC_NOINIT_ATTR uint8_t ip_addr3;
static RTC_NOINIT_ATTR uint8_t ip_addr4;

// IPAddress ip(192, 168, 1, 177);
IPAddress ip;
// static RTC_NOINIT_ATTR

// Initialize the Ethernet server library
// with the IP address and port you want to use
// (port 80 is default for HTTP):
#define ETH_PORT 2048

EthernetServer server(ETH_PORT);

uint16_t adc_command = 0;
float adc_voltage = 0;
uint32_t adc_code = 0;
float LTC2449_lsb = 0.0001;
int32_t LTC2449_offset_code = 0;
int iteration = 0;
uint16_t adc_command_swipe[16];
uint32_t adc_code_swipe[16];
float adc_voltage_swipe[16];
float adc_voltage_corrected[16];
float adc_corr_value_per_channel[16] = {
    8.5409912,
    8.52350766,
    8.521256932,
    8.557979182,
    8.513388735,
    8.509460083,
    8.500493908,
    8.520694435,
    8.529703297,
    8.501053741,
    8.53929611,
    8.526322743,
    8.503854009,
    8.521819502,
    8.542121633,
    8.486522025};

SPIClass *spi3 = NULL;

// ESP NOW structure
typedef struct struct_message
{
  uint8_t mess_int;
  float mess_float[16];
  uint32_t mess_time;
} struct_message;

struct_message mess_struct;

JsonDocument board;

int data_good = 0;
int rssi_display;

void beginSPI3()
{
  spi3 = new SPIClass(HSPI);
  // todo: set miso as spi_miso_bus_fun
  spi3->begin(SPI3_CLK, SPI3_MISO, SPI3_MOSI, SPI3_CS);
  pinMode(spi3->pinSS(), OUTPUT); // HSPI SS
  // pinMode(SPI3_MISO, INPUT); // arduino framework problem 3.x not setting MISO pinmode when communicating with adc
}

void adc_command_prep()
{
  adc_command_swipe[0] = LTC2449_CH0;
  adc_command_swipe[1] = LTC2449_CH1;
  adc_command_swipe[2] = LTC2449_CH2;
  adc_command_swipe[3] = LTC2449_CH3;
  adc_command_swipe[4] = LTC2449_CH4;
  adc_command_swipe[5] = LTC2449_CH5;
  adc_command_swipe[6] = LTC2449_CH6;
  adc_command_swipe[7] = LTC2449_CH7;
  adc_command_swipe[8] = LTC2449_CH8;
  adc_command_swipe[9] = LTC2449_CH9;
  adc_command_swipe[10] = LTC2449_CH10;
  adc_command_swipe[11] = LTC2449_CH11;
  adc_command_swipe[12] = LTC2449_CH12;
  adc_command_swipe[13] = LTC2449_CH13;
  adc_command_swipe[14] = LTC2449_CH14;
  adc_command_swipe[15] = LTC2449_CH15;

  for (int i = 0; i < 15; i++)
  {
    // adc_command_swipe[i] = adc_command_swipe[i] | LTC2449_OSR_8192 | LTC2449_SPEED_1X;
    adc_command_swipe[i] = adc_command_swipe[i] | LTC2449_OSR_256 | LTC2449_SPEED_1X;
  }
}

void adc_command_change(int new_osr) // not working right now
{
  int set_osr = new_osr;
  // clear osr setting from command_swipe
  for (int i = 0; i < 15; i++)
  {
    adc_command_swipe[i] = adc_command_swipe[i] & 0xFF00;
  }
  // setting 32768 because of irregular register mapping
  if (new_osr == 32768)
  {
    for (int i = 0; i < 15; i++)
    {
      adc_command_swipe[i] = adc_command_swipe[i] | LTC2449_OSR_32768;
    }
    Serial.println("Changed OSR to 32768");
    return;
  }

  int osr = 0;
  while (!(new_osr % 2))
  {
    osr++;
    new_osr = new_osr >> 1;
#ifdef DEBUG
    Serial.println(new_osr);
    Serial.println(osr);
// delay(100);
#endif
  }

#ifdef DEBUG
  Serial.print("After while loop: ");
  Serial.println(new_osr);
  Serial.println(osr);
#endif

  osr = osr - 5;
  osr = osr << 4;

#ifdef DEBUG
  Serial.print("osr in hex: ");
  Serial.println(osr, HEX);
#endif

  for (int i = 0; i < 15; i++)
  {
    adc_command_swipe[i] = adc_command_swipe[i] | osr;
  }
  Serial.print("Changed OSR to ");
  Serial.println(set_osr);
  return;
}

void adc_voltage_correction()
{
  for (int i = 0; i <= 15; i++)
    adc_voltage_corrected[i] = adc_voltage_swipe[i] * adc_corr_value_per_channel[i];
}

bool adc_swipe_active_flag = 0;

void adc_data_to_json()
{
  board["board"][0]["id"] = 0;
  for (int i = 0; i < 16; i++)
  {
    String key = "CH" + String(i);
    board["board"][0]["voltages"][key] = adc_voltage_corrected[i];
  }
  board["board"][0]["time"] = millis();

#ifdef DEBUG
  // serializeJsonPretty(board, Serial);
#endif
}

void adc_swipe_channels()
{
  adc_swipe_active_flag = 1;
  uint64_t a = millis(), b = 0;
  if (LTC2449_EOC_timeout(LTC2449_CS, 1000, spi3))                          // Check for EOC
    return;                                                                 // Exit if timeout is reached
  LTC2449_read(LTC2449_CS, adc_command_swipe[0], &adc_code_swipe[0], spi3); // clear buffer, send ch0 command to prepare next result

  for (int i = 0; i < 15; i++)
  {
    if (LTC2449_EOC_timeout(LTC2449_CS, 1000, spi3))                              // Check for EOC
      return;                                                                     // Exit if timeout is reached
    LTC2449_read(LTC2449_CS, adc_command_swipe[i + 1], &adc_code_swipe[i], spi3); // ch[i] result, send next chan command
    adc_voltage_swipe[i] = LTC2449_code_to_voltage(adc_code_swipe[i], LTC2449_lsb, LTC2449_offset_code);
  }
  if (LTC2449_EOC_timeout(LTC2449_CS, 1000, spi3))                           // Check for EOC
    return;                                                                  // Exit if timeout is reached
  LTC2449_read(LTC2449_CS, adc_command_swipe[0], &adc_code_swipe[15], spi3); // clear buffer, send ch0 command to prepare next result
  adc_voltage_swipe[15] = LTC2449_code_to_voltage(adc_code_swipe[15], LTC2449_lsb, LTC2449_offset_code);
  b = millis();
  adc_voltage_correction();
#ifdef DEBUG
  Serial.print("Swipe time: ");
  Serial.println(b - a);
#endif
  adc_data_to_json();
  adc_swipe_active_flag = 0;
}

void adc_ch0_test()
{
  uint16_t miso_timeout = 1000;
  adc_command = LTC2449_CH0 | LTC2449_OSR_32768 | LTC2449_SPEED_1X; // Build ADC command for channel 0
                                                                    // OSR = 32768*2 = 65536
  if (LTC2449_EOC_timeout(LTC2449_CS, miso_timeout, spi3))
  { // Check for EOC
    Serial.println("Timeout");
    return;
  } // Exit if timeout is reached
  LTC2449_read(LTC2449_CS, adc_command, &adc_code, spi3);                            // Throws out last reading
  adc_voltage = LTC2449_code_to_voltage(adc_code, LTC2449_lsb, LTC2449_offset_code); // Convert adc_code to voltage
  Serial.print("CH0: ");
  Serial.println(adc_voltage, 9);
}

void recv_data_print()
{
#ifdef DEBUG
  Serial.print("Bytes received: ");
  Serial.println(sizeof(mess_struct));
  Serial.print("Char: ");
  Serial.println(mess_struct.mess_int);
  for (int i = 0; i < 16; i++)
  {
    Serial.print("CH");
    Serial.print(i);
    Serial.print(": ");
    Serial.println(mess_struct.mess_float[i]);
  }
  Serial.print("Time: ");
  Serial.println(mess_struct.mess_time);
  Serial.print("RSSI: ");
  Serial.println(rssi_display);
  Serial.println();
#endif
  data_good = 0;
}

void promiscuous_rx_cb(void *buf, wifi_promiscuous_pkt_type_t type)
{
  // All espnow traffic uses action frames which are a subtype of the mgmnt frames so filter out everything else.
  if (type != WIFI_PKT_MGMT)
    return;

  const wifi_promiscuous_pkt_t *ppkt = (wifi_promiscuous_pkt_t *)buf;
  // const wifi_ieee80211_packet_t *ipkt = (wifi_ieee80211_packet_t *)ppkt->payload;
  // const wifi_ieee80211_mac_hdr_t *hdr = &ipkt->hdr;

  int rssi = ppkt->rx_ctrl.rssi;
  rssi_display = rssi;
}

uint32_t old_mess_time = 0;
// callback function that will be executed when data is received
void OnDataRecv(const uint8_t *mac_addr, const uint8_t *incomingData, int len)
{
  // Copies the sender mac address to a string
  char macStr[18];
  snprintf(macStr, sizeof(macStr), "%02x:%02x:%02x:%02x:%02x:%02x",
           mac_addr[0], mac_addr[1], mac_addr[2], mac_addr[3], mac_addr[4], mac_addr[5]);
  memcpy(&mess_struct, incomingData, sizeof(mess_struct));

  /*// ESP NOW structure
  typedef struct struct_message
  {
    uint8_t mess_int;
    float mess_float[16];
    uint32_t mess_time;
  } struct_message;

  struct_message mess_struct;*/

  board["board"][mess_struct.mess_int]["id"] = mess_struct.mess_int;
  for (int i = 0; i < 16; i++)
  {
    String key = "CH" + String(i);
    board["board"][mess_struct.mess_int]["voltages"][key] = mess_struct.mess_float[i];
  }
  board["board"][mess_struct.mess_time]["time"] = mess_struct.mess_time;
}

uint32_t ip_addr32;

TaskHandle_t AdcSwipeHandle;

void AdcSwipeCode(void *pvParameters)
{
  for (;;)
  {
    esp_task_wdt_reset();
    if (!adc_swipe_active_flag)
    {
      adc_swipe_channels();
    }
    delay(10);
  }
}

TaskHandle_t EthernetServerHandle;

#define WDT_TIMEOUT 5

void EthernetServerCode(void *pvParameters)
{
  for (;;)
  {
    esp_task_wdt_reset();
    //  Serial.print("Ethsrvr from task on core: ");
    //  Serial.println(xPortGetCoreID());
    char incbuff[BUFSIZ];
    int index = 0;
    // listen for incoming clients
    EthernetClient client = server.available();
    if (client)
    {
      Serial.println("new client");
      // an HTTP request ends with a blank line
      bool currentLineIsBlank = true;
      while (client.connected())
      {
        // watchdog reset
        esp_task_wdt_reset();
        if (client.available())
        {
          esp_task_wdt_reset();
          char c = client.read();
          Serial.write(c);
          Serial.print(" ");
          if (c == '\n' && currentLineIsBlank)
          {
            // send a standard HTTP response header
            client.println("HTTP/1.1 200 OK");
            client.println("Content-Type: text/html");
            client.println("Connection: close"); // the connection will be closed after completion of the response
            client.println("Refresh: 15");       // refresh the page automatically every 5 sec
            client.println();
            client.println("<!DOCTYPE HTML>");
            client.println("<html>");
            // adc_swipe_channels();
            // for (int i = 0; i < 16; i++)
            // {
            //   client.print("Channel ");
            //   client.print(i + 1);
            //   client.print(": ");
            //   client.print(adc_voltage_swipe[i], 9);
            //   client.println("<br />");
            // }
            serializeJson(board, client);
            client.println("</html>");
            break;
          }
          if (c == '?')
          {
            // client.println("PROBE_1 data: ");
            // for (int i = 0; i < 16; i++)
            // {
            //   client.print(i + 1);
            //   client.print(": ");
            //   client.println(adc_voltage_corrected[i], 6);
            // }
            serializeJson(board, client);
          }
          if (c == '\n')
          {
            // you're starting a new line
            currentLineIsBlank = true;
          }
          else if (c != '\r')
          {
            // you've gotten a character on the current line
            currentLineIsBlank = false;
          }
        }
      }
      // give the web browser time to receive the data
      delay(1);
      // close the connection:
      client.stop();
      Serial.println("client disconnected");
    }
  }
}

void setup()
{
  esp_task_wdt_init(WDT_TIMEOUT, true);
  esp_task_wdt_add(EthernetServerHandle);
  esp_task_wdt_add(AdcSwipeHandle);
  esp_task_wdt_add(NULL);
  // esp_task_wdt_delete(NULL);

  ip_addr1 = 192;
  ip_addr2 = 168;
  ip_addr3 = 137;
  ip_addr4 = 50;
  ip_addr32 = (ip_addr4 << 24) + (ip_addr3 << 16) + (ip_addr2 << 8) + ip_addr1;

  ip = ip_addr32;
  // Open serial communications and wait for port to open:
  Serial.begin(115200);

  beginSPI3();

  pinMode(ADC_BUSY_PIN, INPUT);
  pinMode(ADC_EXT_CLK_PIN, OUTPUT);
  digitalWrite(ADC_EXT_CLK_PIN, LOW);

  // LTC2449_cal_voltage(0x55CC00, 0x1853177, 0, 1.5, &LTC2449_lsb, &LTC2449_offset_code);
  // LTC2449_cal_voltage(0x200D6400, 0x30000000, 0, 1.25, &LTC2449_lsb, &LTC2449_offset_code);
  LTC2449_cal_voltage(0x200D0000, 0x30000000, 0, 2.048, &LTC2449_lsb, &LTC2449_offset_code);

  adc_command_prep();

  // osr set
  delay(100);
  // adc_command_change(8196); //osr can be between 128 and 32768, so between 1<<(7+(0-8))

  delay(2000); //
  pinMode(W5500_INT, INPUT);
  pinMode(W5500_INT, PULLUP);
  pinMode(W5500_RST, OUTPUT);
  pinMode(W5500_RST, PULLUP);
  digitalWrite(W5500_RST, HIGH);

  digitalWrite(W5500_RST, LOW);
  delay(10);
  digitalWrite(W5500_RST, HIGH);
  delay(10);

  Ethernet.init(SPI2_CS);

  Serial.println("Ethernet WebServer Example");

  // start the Ethernet connection and the server:
  Ethernet.begin(mac, ip);

  // Check for Ethernet hardware present
  if (Ethernet.hardwareStatus() == EthernetNoHardware)
  {
    Serial.println("Ethernet shield was not found.  Sorry, can't run without hardware. :(");
    while (true)
    {
      delay(1); // do nothing, no point running without Ethernet hardware
    }
  }
  if (Ethernet.linkStatus() == LinkOFF)
  {
    Serial.println("Ethernet cable is not connected.");
  }

  // start the server
  server.begin();
  Serial.print("server is at ");
  Serial.println(Ethernet.localIP());

  xTaskCreatePinnedToCore(AdcSwipeCode, "AdcSwipeHandle", 10000, NULL, 1, &AdcSwipeHandle, 0);
  xTaskCreatePinnedToCore(EthernetServerCode, "EthernetServerHandle", 10000, NULL, 1, &EthernetServerHandle, 1);

  // esp now init
  WiFi.mode(WIFI_STA);

  // Init ESP-NOW
  if (esp_now_init() != ESP_OK)
  {
    Serial.println("Error initializing ESP-NOW");
    return;
  }

  esp_now_register_recv_cb(esp_now_recv_cb_t(OnDataRecv));

  esp_wifi_set_promiscuous(true);
  esp_wifi_set_promiscuous_rx_cb(&promiscuous_rx_cb);
}

void loop()
{
  esp_task_wdt_reset();
#ifdef DEBUG
  Serial.print("Main loop on core: ");
  Serial.println(xPortGetCoreID());
#endif
  delay(2000);
  serializeJsonPretty(board, Serial);
  delay(2000);
  // if (data_good == 1)
  // {
  //   recv_data_print();
  // }
}

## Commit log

2024-12-04 add pcb files
    [MagInputs.kicad_sch, PowerSupply.kicad_sch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]
2024-12-04 probe code 23-10
2024-12-04 probe code 29-11
2024-12-04 probe code 04-12
2024-12-11 Revert to framework arduino-esp32 2.0.17 because of spi3 miso problem
    [main.cpp]
2024-12-11 Case DXF files
    [fpbp_sonda.dxf]
2024-12-11 Fix found for Arduino 3.x framework
    [main.cpp]
2024-12-13 Per channel reading correction
    [main.cpp]
2025-01-14 Added millis measurement in struct, osr changed to 256
2025-02-12 Merge branch 'main' of https://github.com/dudeku/esp-now-differential-probe into HEAD
    # Conflicts:
    # code/adc-tcp/.gitignore
    # code/adc-tcp/.pio/libdeps/esp32-s3-n8r8-cdc/Ethernet/src/Ethernet.h
    # code/adc-tcp/.pio/libdeps/esp32-s3-n8r8-cdc/Ethernet/src/EthernetServer.cpp
    # code/adc-tcp/.pio/libdeps/esp32-s3-n8r8-cdc/integrity.dat
    # code/adc-tcp/platformio.ini
    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
    [MagInputs.kicad_sch, PowerSupply.kicad_sch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]
2025-02-18 add more vias
    [MagInputs.kicad_sch, PowerSupply.kicad_sch, diffprobe-espnow.kicad_pcb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]
2025-03-11 added simulation, updated pcb designs
    [esp32andadc.kicad_sch, espnow-sonda.kicad_pcb, espnow-sonda.kicad_sch]
2025-03-27 KiCAD 9 update, new psu filtering and adc input signal filtering. More silkscreen writing.
    [MagInputs.kicad_sch, PowerSupply.kicad_sch, diffprobe-espnow.kicad_sch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]
2025-11-01 update sim symbol
    [espnow-sonda.kicad_sch]
2025-11-01 tidying up schematics
    [MagInputs.kicad_sch, PowerSupply.kicad_sch, diffprobe-espnow.kicad_sch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]
2025-11-18 schematic cleanup again
    [MagInputs.kicad_sch, PowerSupply.kicad_sch]
